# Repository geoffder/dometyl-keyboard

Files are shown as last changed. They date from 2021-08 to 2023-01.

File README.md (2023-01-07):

# Dometyl Keyboard

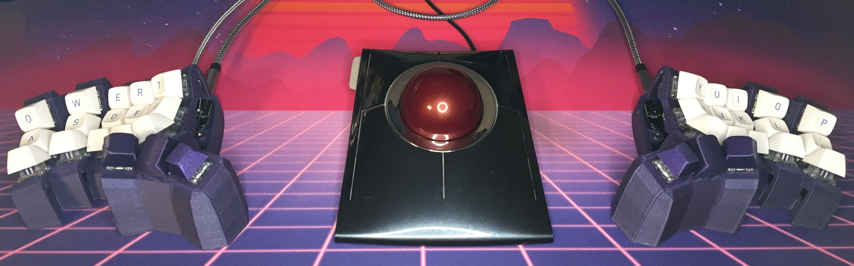
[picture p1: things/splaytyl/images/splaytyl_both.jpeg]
Splaytyl Build


## Another Dactyl inspired keyboard. Supporting MX, Choc, and even rubber domes.
This is a library for generating paramaterized split-hand, concave, columnar,
ergonomic keyboards in the spirit of the
[Dactyl](https://github.com/adereth/dactyl-keyboard), but written from the
ground up in [ocaml](https://ocaml.org/), rather than
[clojure](https://clojure.org). **Dometyl** also takes inspiration from a
lineage of **Dactyl-like** keyboards that evolved from the original script,
including the [Compactyl](https://github.com/dereknheiley/dactyl-manuform-tight)
itself a fork of forks of dactyl-manuform keyboards with many accumulated
features, and the [Skeletyl](https://github.com/Bastardkb/Skeletyl), a sleak,
low-profile, open-case design built in
[Fusion360](https://www.autodesk.ca/en/products/fusion-360/overview).

The name **(rubber) dometyl** comes from this library's introduction of a means
of building split-hand concave keyboards with rubber domes. Taking advantage of
the readily available [Niz housing and
sliders](https://www.nizkeyboard.com/products/2019-new-niz-ec-switch), and
third-party non-sheet rubber domes (e.g. [DES BKE
DOMES](https://www.apexkeyboards.ca/products/des-domes-bke-tactile)), we can
build dome-with-slider switches of our own without canabilizing an existing
Topre or Niz board. You may be thinking that we still need expensive to obtain
conical springs, and difficult to design (and *very* difficult to make use of
inside a curved case) electro capacitive sensing PCBs to complete the picture,
but then you would be wrong! One need simply glue magnets to sliders, and glue
[hall-effect sensors](https://www.diodes.com/assets/Datasheets/AH3572.pdf) into
a case, and *voila* the rubber dometyl is born.

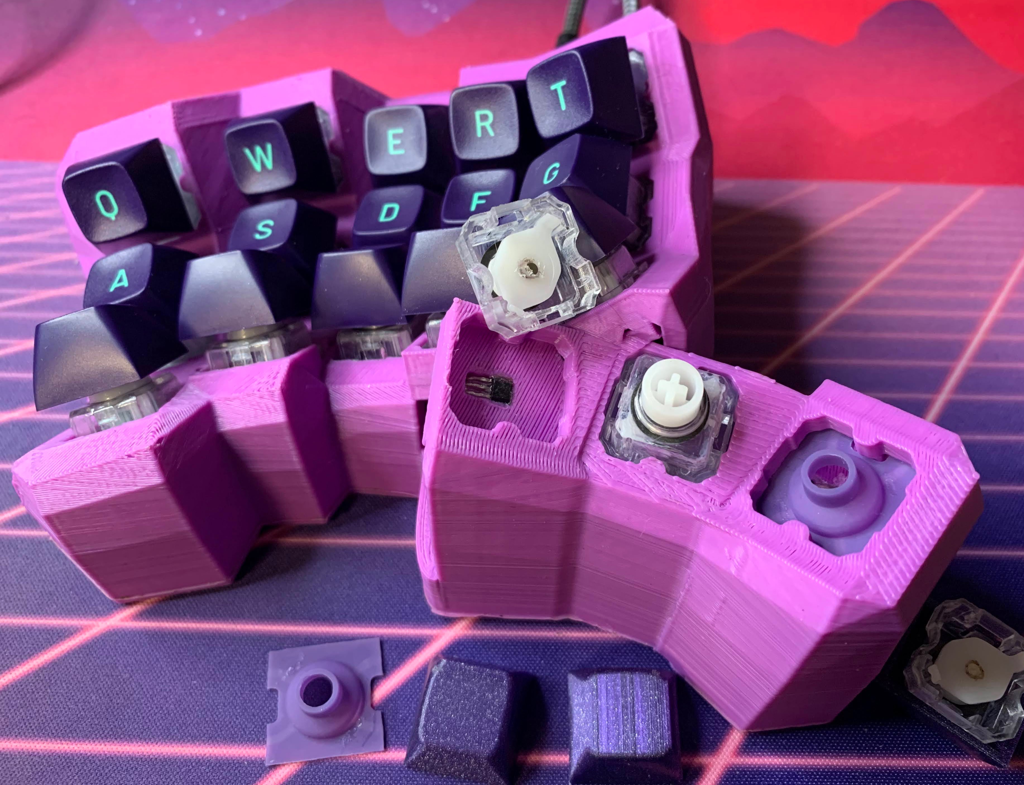
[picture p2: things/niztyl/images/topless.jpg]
niztyl - gone topless


The relevant code for generating the required keyhole can be found in the [Niz
module](lib/niz.ml), the first example of a board
configuration using them [here](models/examples/niztyl.ml), and the build
showcase for it [here](things/legacy/niztyl).

Of course, if you aren't an insane person, the dometyl generator also supports
more civilized Mx and Choc switch options.

## Setup
This generator is written in [ocaml](https://ocaml.org/), so you'll need to get
an environment set up, including the package manager
[opam](https://opam.ocaml.org/) and the build system
[dune](https://github.com/ocaml/dune) (which we'll install through opam). You'll
of course also want [OpenSCAD](https://openscad.org/) to preview/render/export
the generated models (see [OpenSCAD configuration](#openscad-configuration) for tips).

After installing `opam`, and confirming that you are in this branch, you can run
the [setup.sh](setup.sh) script for convenience, or follow the instructions
under the [opam dependencies](#opam-dependencies) sub-section.

### opam dependencies
All dependencies are available from the opam package manager including the build
system [dune](https://github.com/ocaml/dune), and of course
[OCADml](https://github.com/OCADml/OCADml),
[OSCADml](https://github.com/OCADml/OSCADml)
and [ppx_deriving_cad](https://github.com/OCADml/ppx_deriving_cad) for the
modelling. I'd also recommend that you pick up the listed dev tools (which
you'll want to get the corresponding packages/plugins for in your editor of
choice).

**Required:**
From this folder (repo root):
* `opam install . --deps-only --with-doc`
* `dune build`

**Highly recommended for dev experience:**
* `opam install merlin ocp-indent ocaml-lsp-server ocamlformat ocamlformat-rpc`

## OpenSCAD configuration
It is **highly recommended** that you use a [development snapshot](https://openscad.org/downloads.html) of OpenSCAD,
rather than whatever version your package manager may have for you. Then under
the `Features` tab in `Edit/Preferences` and check the following:
- `fast-csg`, `fast-csg-trust-corefinement`, `fast-csg-remesh`,
  `fast-csg-remesh-predictability`, `lazy-union`, `vertex-object-*`
The newly added `fast-csg` and related features speed up rendering considerably,
making the development cycle much more pleasant

## Documentation
API documentation and usage guides are available
[online](https://geoffder.github.io/dometyl-keyboard/dometyl/index.html).

## Usage
1. Make a new `.ml` file in [models](models), maybe
   starting with a copy of and existing one and and modifying it to suit your
   preferences / fit your hand.
2. Modify [main.ml](models/main.ml), adding lines to generate and write
   your case models/parts to file with `Scad.to_file`.
3. Run your [main.ml](models/main.ml) with `dune build @models` from the [dometyl](dometyl)
   project folder. Any `.scad` files produced will then appear in the
   [models](models/scads) directory. For a more fluid experience, you
   can install `fswatch` (cross-platform) or `inotify` (GNU/linux) on your
   system, and use `dune build -w @models` to automatically build and execute on
   file changes.
4. Open generated `.scad` files in OpenSCAD where they can be
   previewed/rendered/exported to `.stl`. If a viewed `.scad` is overwritten by
   compiling and running the generator, the changes will be visible in the GUI.

### Direct Export
`dune build @export_models` is also made available for convenient batch `stl`
export. When run, this rule will call out to the `openscad` cli (assumed to be
installed on your system) to asynchronously export *all* of the `scad` files in
[models](models/scads) directory to `stl` models in the
[models](models/stls) directory at once.

**Note:**
- Enabling `fast-csg` and the like is not currently supported by the `OSCADml`
  CLI helpers.
- STL export can take quite a while (which is why this can be helpful) and
 consume a lot of resources, so one should be mindful of what one is signing up
 for by building this rule.
- Unfortunately, CLI export sometimes fails in CGAL when the same model would
 pass via the GUI.

## Example Output
* An uglier [recreation](models/examples/skeletyl.ml) (yellow) of the
  [BastardKB Skeletyl v4](https://github.com/Bastardkb/Skeletyl) (purple).
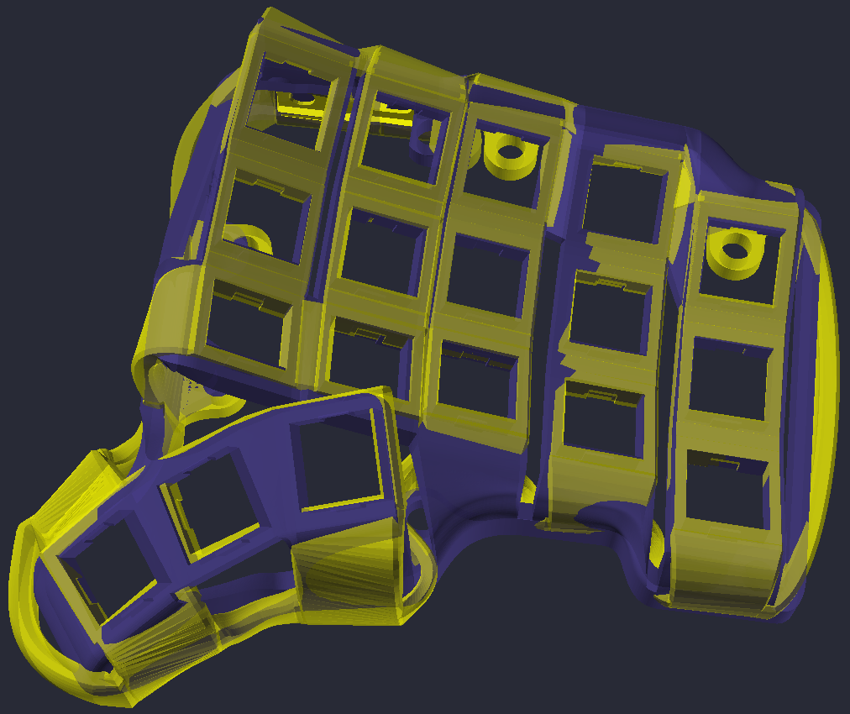
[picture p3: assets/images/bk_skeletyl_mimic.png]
bk skeletyl comparison
  
  This configuration can be a good place to start if what you are looking for is
  minor tweaks to more "standard" dactyl-like curvatures and offsets (or you want hotswap
  sockets).
* Configurable heat-set insert screw holes, magnet insets, or bumpon feet can be
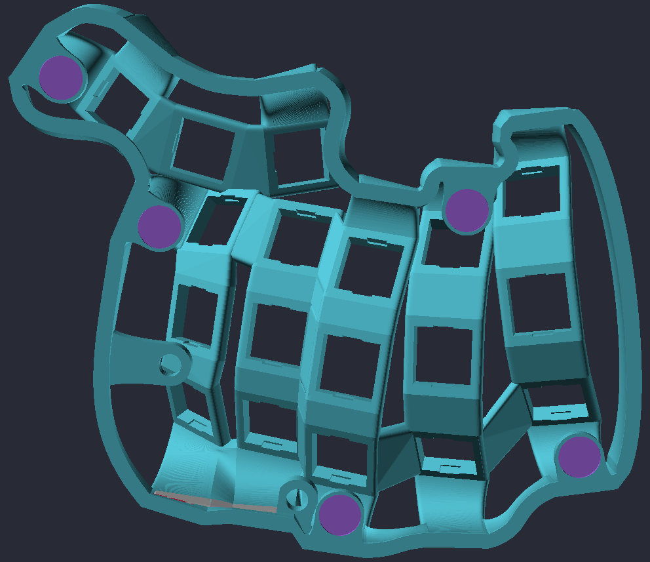
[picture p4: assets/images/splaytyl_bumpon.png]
splaytyl bumpon view
  placed at the base of walls of your choosing 
* Base plates and configurable tents can be generated to fit your case, using
  either screws (into brass insets in the case), or magnets for mounting.
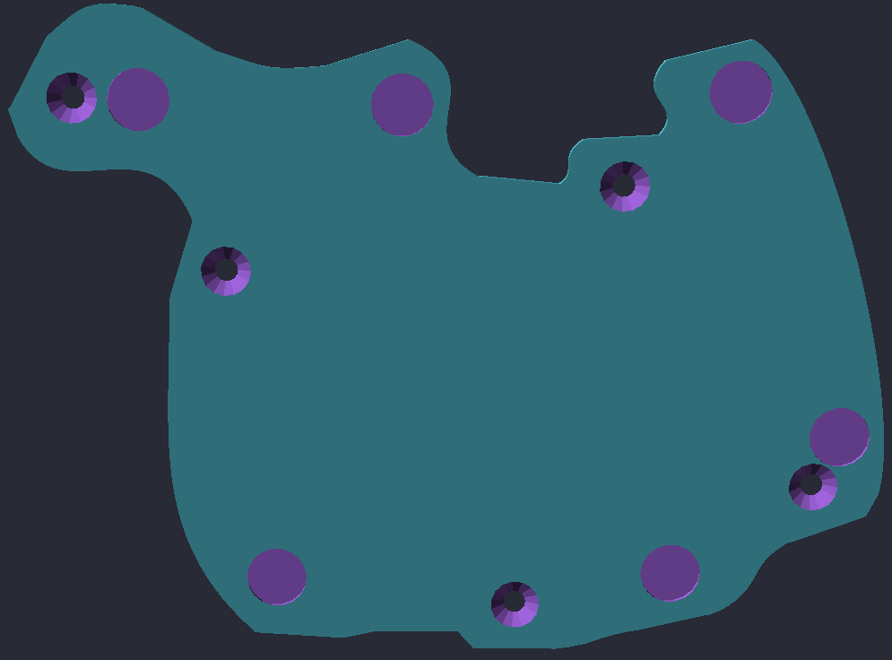
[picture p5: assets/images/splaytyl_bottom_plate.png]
splaytyl bottom plate
  
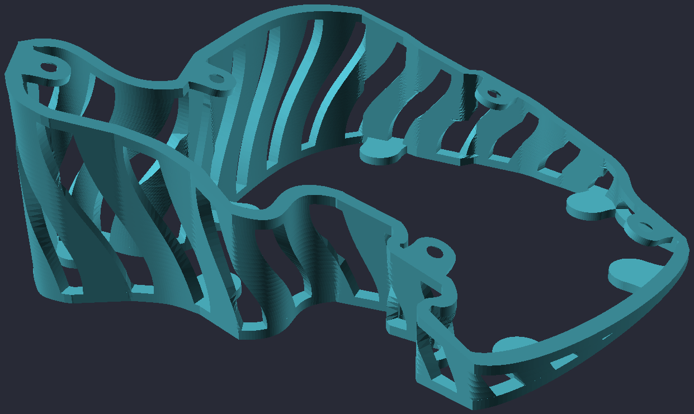
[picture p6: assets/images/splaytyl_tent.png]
splaytyl tent
  

## Builds / STLs
There is a showcase of finished builds and some example STLs [here](things), including some
pictures, bills of materials, and notes. If you've designed and built a board
with the dometyl generator, and you are happy with it, please consider contributing the
configuration to the [models](models) directory, and adding a folder
to the [boards showcase](things).

## MCU / TRRS jack holders
* A few solutions for MCU (elite-C and pro-micro currently) and TRRS jack
  mounting are available at the moment. Rough placement is done with the help of
  coordinates kept within the records of the `Case.t` type, with offset and
  rotation parameters available to fine-tune.
* Firstly, there is support for using the familiar slot-in trays from
  [dereknheiley](https://github.com/dereknheiley/dactyl-manuform-tight)
  (reversible, elite-C without and without reset button access) and
  [carbonfet](https://github.com/carbonfet/dactyl-manuform) (non-reversible,
  elite-C and pro-micro). Eventually a more tailored tray holder that should be
  available, but these existing stls can get the job done today.
* Second, the [BastardKB shield
  pcb](https://github.com/Bastardkb/Elite-C-holder) used in the
  [Skeletyl](https://github.com/Bastardkb/Skeletyl) (as well Quentin's other
  boards) is supported as well. In addition to making the required insets/holes
  in the case, the included helper functions will place configurable eyelets for
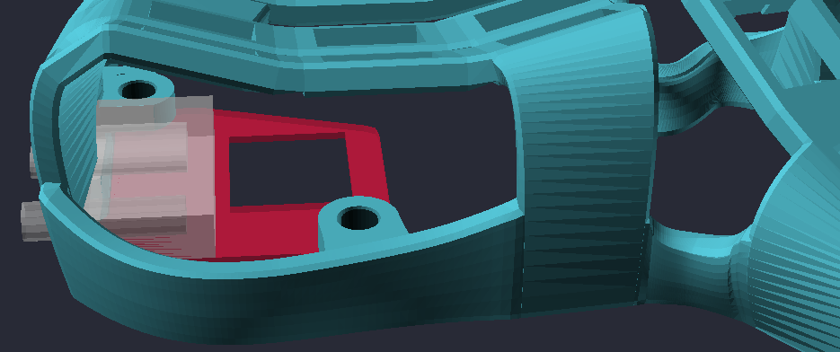
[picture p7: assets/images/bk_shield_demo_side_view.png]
BK shield side-view
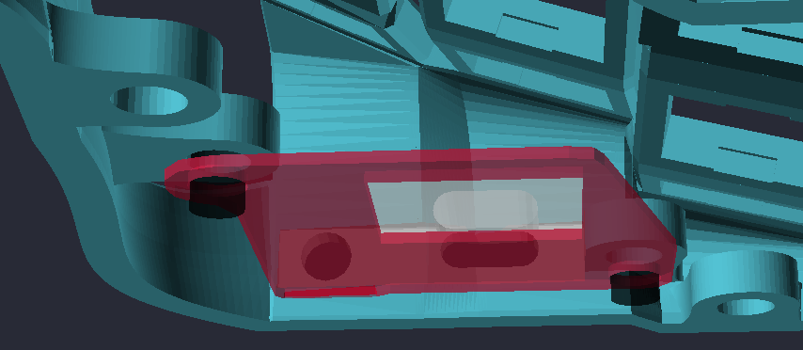
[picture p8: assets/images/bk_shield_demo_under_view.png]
BK shield under-view
  heatset inserts for mounting.  
  Some time ago, I ordered way too many of these off of JLCPCB, so if you are in
  NA, something could likely be arranged! Alternatively, if would like to use
  this mounting method rather than one of the trays, and you don't want get PCBs
  made, there is an [stl](assets/mcu_holders/bastardkb/printable_shield_right.stl)
  available which you can print and solder your components around / glue to.
* When using one of the trays, be mindful that the rails/slots are cut nicely in
  the wall, and for an option that cuts ports into the wall, be sure that they
  don't start too far away from the outside, so that the plugs will be able to
  reach. `Walls.make` has an `index_scale` parameter so that these
  holder-relevant walls can be tuned separately from the rest to adapt to your
  chosen mounting method.

## The Hand
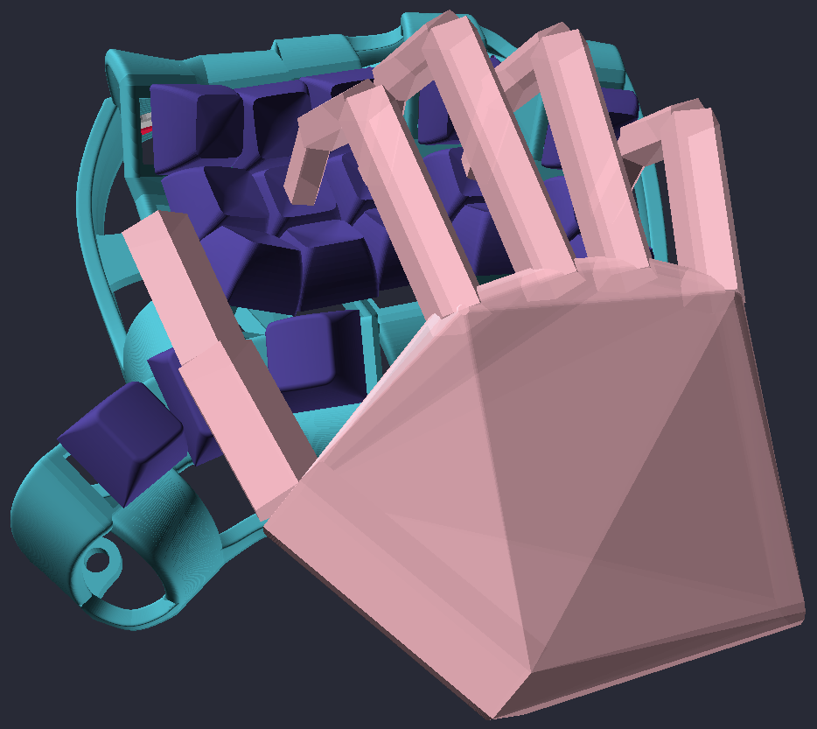
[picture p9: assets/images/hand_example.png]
Hand

There is an as yet undocumented (and subject to evolution) [Hand
module](lib/hand.ml) available to play around with. One can
generate hand from knuckle (base of proximal bones, or the meta-carpal for the
thumb) offset coordinates and bone lengths, then pose it with the available
flexion/extension/abduction/adduction/etc functions, and place it over the home
row of a generated `Plate.t`. Hopefully this can help give you a sense of what
column offsets and curvatures are going to work for you before you commit to a
test print.

## Troubleshooting
Now and then, when you attempt to render a model, part of it will disappear.
This is due to my imperfect abuse of
[OpenSCAD
polyhedrons](https://en.m.wikibooks.org/wiki/OpenSCAD_User_Manual/Primitive_Solids#polyhedron),
which can sometimes self-intersect despite the so-far built-in preventative
efforts. The walls (from keyholes to the ground) and the connections between the
walls both use polyhedrons so they are prone to breaking in this manner.

When this happens, and more than one piece of the case disappears (e.g. all of the
connections between the walls), it can be useful to narrow down which part(s) in
particular caused it, since it isn't necessarily all of them that have gone bad.
To help with this, you can use **Thrown Together** mode in the OpenSCAD GUI
(found in the **View** menu, or activated by hitting **F12**), which will show
pink where you can see into the inside of any shapes (unclosed mesh).

Generally, you should be able to fix the problem by adjusting the parameters
used for drawing the polyhedrons in question, such as scaling walls to prevent
them overlapping with eachother, adjusting resolution with `~fn` parameters, etc.

## Contributing
Contributions extending the functionality of the library (in addition to board
configurations as mentioned above) are welcome. If you plan to make a PR, please
have autoformatting working with your editor working (using the `.ocamlformat`
profile included in this repo) beforehand, and ammend/write doc comments in the
relevant interface files (already not 100% as is).

## License
Copyright © 2023 Geoff deRosenroll

The source code for generating the models is distributed under the [GNU AFFERO
GENERAL PUBLIC LICENSE Version 3](LICENSE.md).

The generated models are distributed under the [Creative Commons
Attribution-ShareAlike 4.0 International (CC BY-SA 4.0)](LICENSE-models.md).

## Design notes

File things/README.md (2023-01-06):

Some of the builds here were made with the original formulation
of the dometyl generator (preserved in the #legacy branch). For now, the old stl
files have been moved into **legacy** sub-directories, with updated stls
replacing them at the top-level of their respective directories.

The cases/parts generated by the current iteration are not *really*
fundamentally different however, so the readme guides within should still be
helpful regardless.

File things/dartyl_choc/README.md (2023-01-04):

# Dartyl Choc Edition

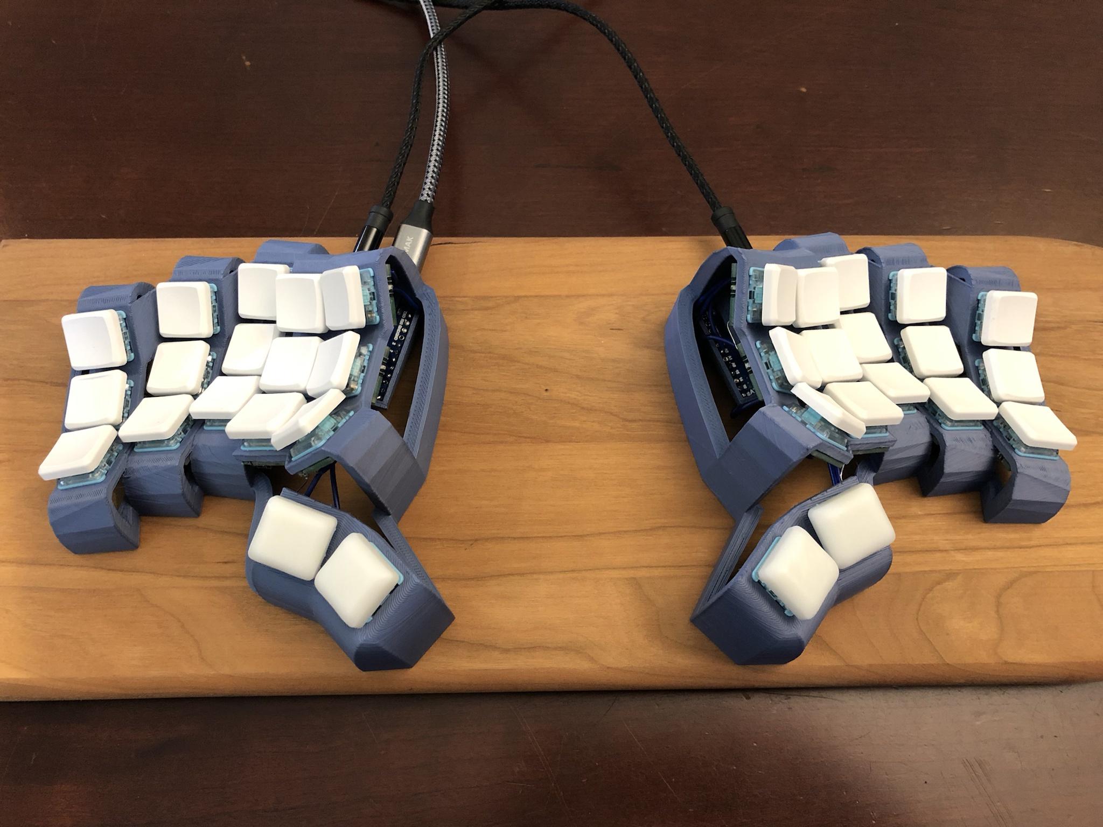
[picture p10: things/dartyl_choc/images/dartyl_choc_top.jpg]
Dartyl Choc - Top

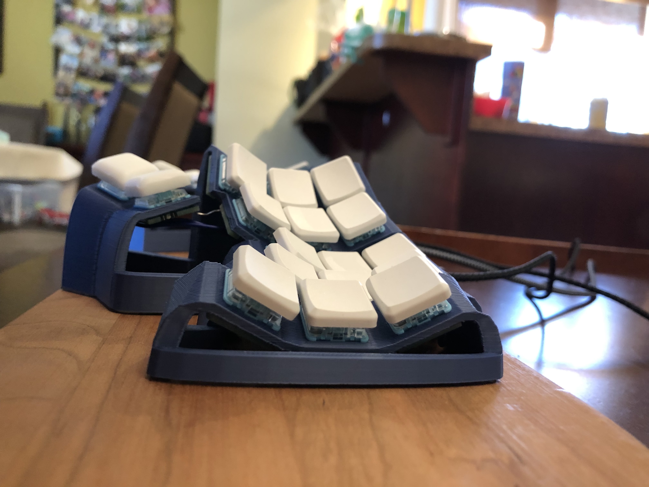
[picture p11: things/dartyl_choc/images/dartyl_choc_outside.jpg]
Dartyl Choc - Outside

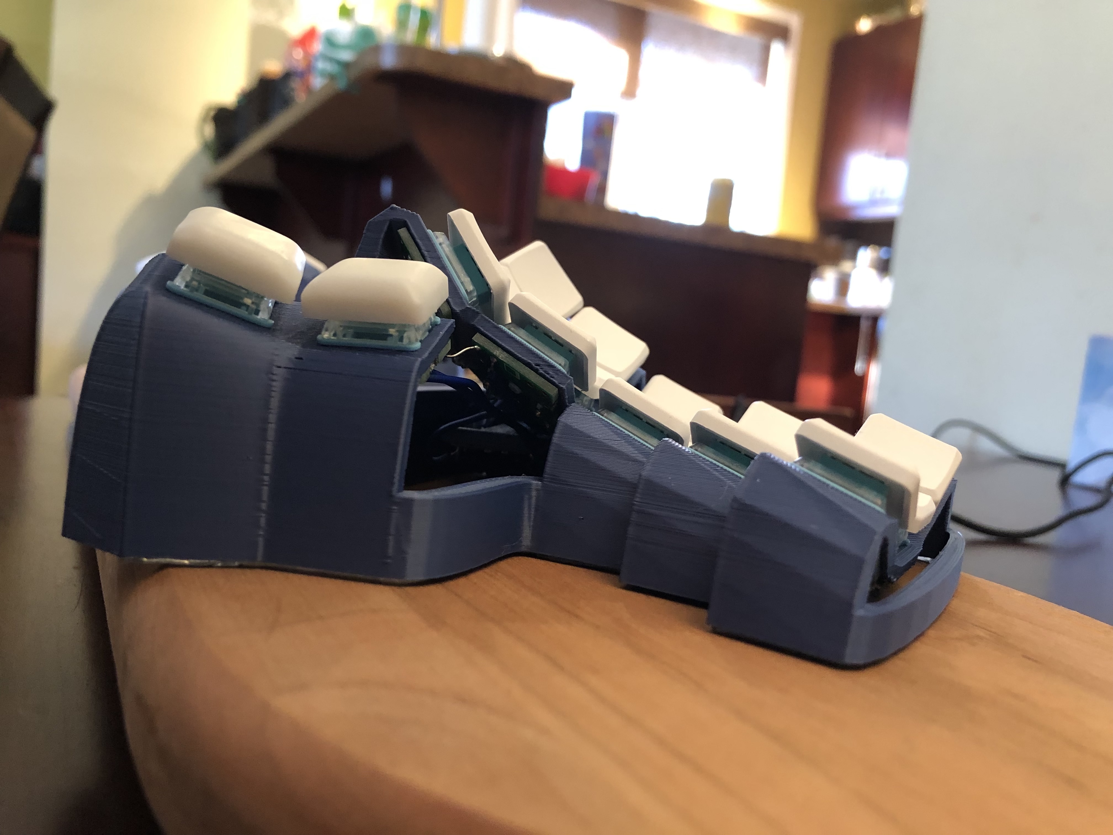
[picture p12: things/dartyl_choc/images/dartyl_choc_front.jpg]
Dartyl Choc - Front

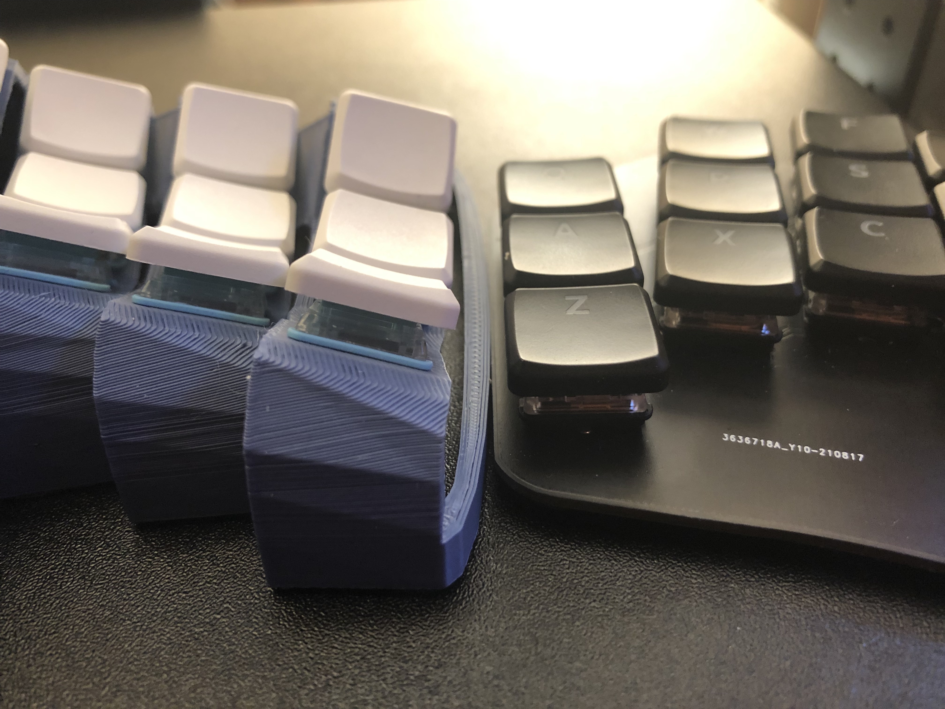
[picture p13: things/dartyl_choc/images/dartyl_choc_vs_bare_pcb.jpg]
Dartyl Choc vs. Bare PCB

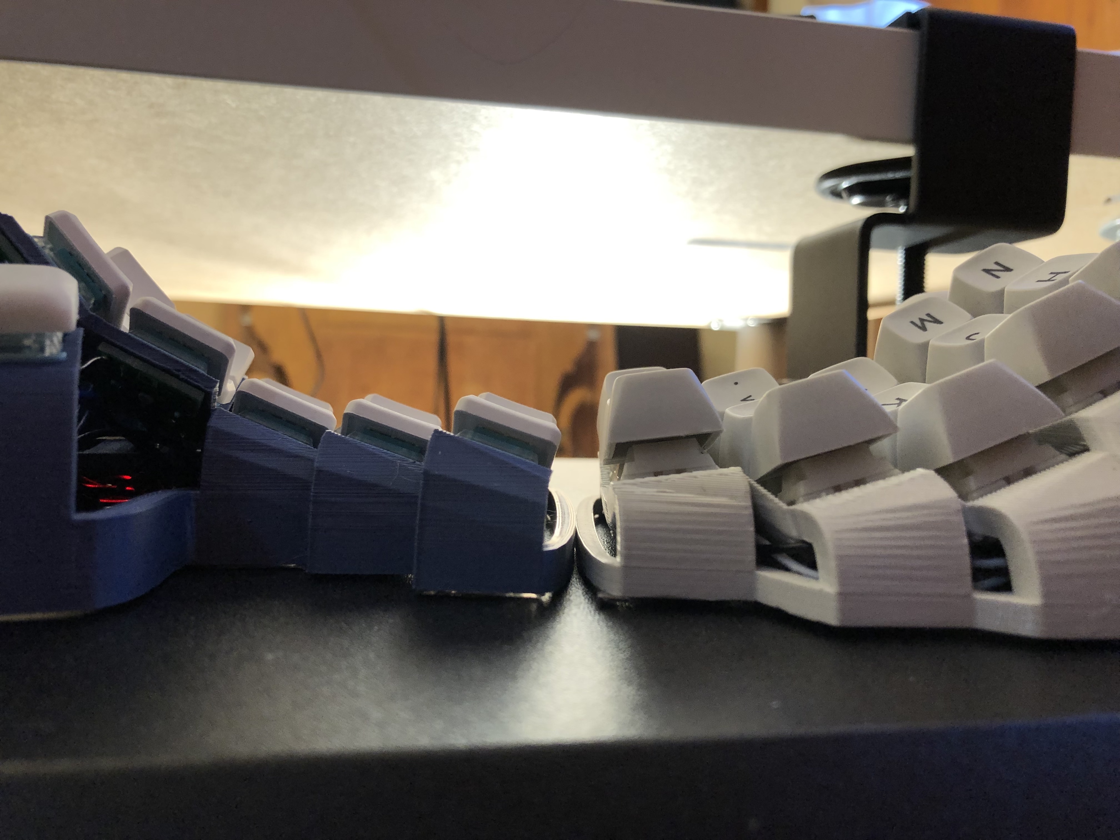
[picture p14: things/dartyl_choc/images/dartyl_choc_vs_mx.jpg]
Dartyl Choc vs. Dartyl MX

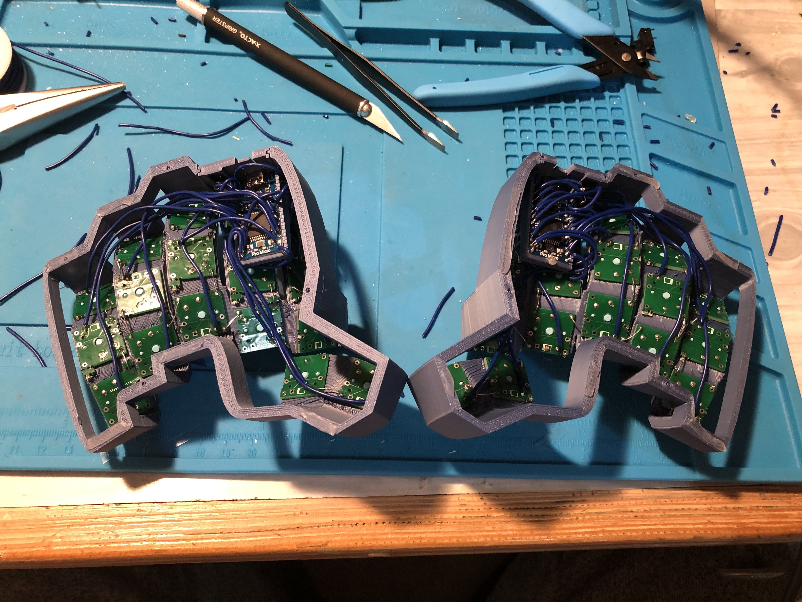
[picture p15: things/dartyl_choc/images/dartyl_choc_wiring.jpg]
Dartyl Choc - Wiring


## Bill of Materials

| Part name | Amount  |
| ---| ---|
| [Cases][case] (left and right) | 2 |
| Choc V1 switches of your choice | 34 |
| Ideally MBK caps for alphas | 30 / 34 |
| Convex thumb caps, I resin printed [these][talon] (optional) | 4 |
| Choc [1u pcb][pcb]'s (optional) | 34 |
| Pro micro compatible mcu's | 2 |
| Wires (26/28 AWG solid core wire recommended) | some |
| [Audio jack][trrs], through hole | 2 |
| USB cable for the mcu you used | 1 |
| TRRS / male-male audio cable | 1 |
| Rubber / Tape | some |
| MCU Holders (see below) | 2 |

## Wiring

This case has 34 keys which means you can use QMK's `DIRECT_PINS` feature instead of wiring a grid with diodes.

## Key Caps

I tried [talon][talon] keycaps but they didn't work with the inner column as supplied, MBK caps are the safest option.

## Grip

I used "[Reusable Double-Sided Adhesive Nano Tape][tape]" for grip and it works very well. I've also used the rubber between bumpons from a sheet of bumpons, but it's not as good.

## MCU Holders

I used a modified version of [this mcu holder](https://github.com/dereknheiley/dactyl-manuform-tight/blob/master/things/usb_holder_w_reset.stl) as the usb-c pro micros are a little longer than the regular pro micros. I've included my modified [holder stl](usb_holder_promicro_usbc.stl) and [scad](usb_holder.scad).

[talon]: https://www.thingiverse.com/thing:4858309
[pcb]: https://github.com/ibnuda/single/tree/master/choc
[trrs]: https://www.aliexpress.com/item/1005001928651798.html
[tape]: https://www.aliexpress.com/item/1005001598557779.html
[case]: dartyl_choc.stl

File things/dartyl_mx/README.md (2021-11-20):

# Dartyl MX Edition

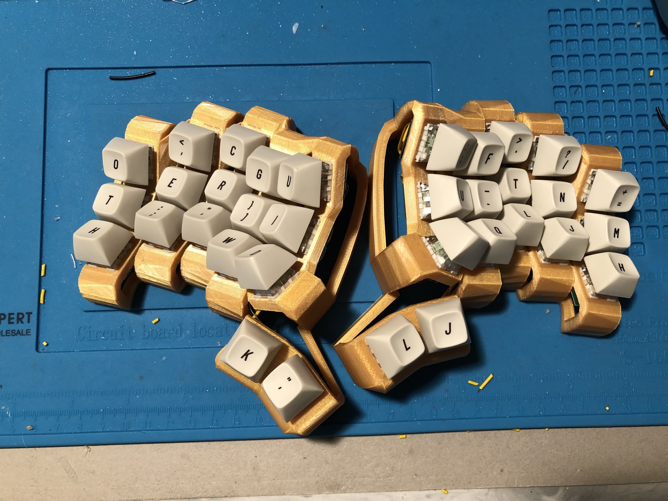
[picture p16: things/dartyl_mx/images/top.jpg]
Dartyl MX - Top


## Bill of Materials

| Part name | Amount  |
| ---| ---|
| [Cases][case] (left and right) | 2 |
| MX switches of your choice | 34 |
| Any MX compatible keycaps should work, I used MT3 | 30 / 34 |
| Convex thumb caps, I resin printed [these][convx] (optional) | 4 |
| MX [1u pcb][pcb]'s (optional) | 34 |
| Pro micro compatible mcu's | 2 |
| Wires (26/28 AWG solid core wire recommended) | some |
| [Audio jack][trrs], through hole | 2 |
| USB cable for the mcu you used | 1 |
| TRRS / male-male audio cable | 1 |
| Rubber / Tape | some |
| MCU Holders (see below) | 2 |

## Wiring

This case has 34 keys which means you can use QMK's `DIRECT_PINS` feature instead of wiring a grid with diodes.

## Key Caps

The [convex keypcap][convx] in the above BOM is credited to [pseudoku](https://github.com/pseudoku/PseudoMakeMeKeyCapProfiles) who also [sells some beautiful custom keycaps](https://www.asymplex.xyz/).

## Grip

I used "[Reusable Double-Sided Adhesive Nano Tape][tape]" for grip and it works very well. I've also used the rubber between bumpons from a sheet of bumpons, but it's not as good.

## MCU Holders

I used a modified version of [this mcu holder](https://github.com/dereknheiley/dactyl-manuform-tight/blob/master/things/usb_holder_w_reset.stl) as the usb-c pro micros are a little longer than the regular pro micros. I've included my modified [holder stl](../dartyl_choc/usb_holder_promicro_usbc.stl) and [scad](../dartyl_choc/usb_holder.scad).

[convx]: MX_DES_Convex_012tol.stl
[pcb]: https://github.com/swanmatch/MxLEDBitPCB/blob/master/readme_en.md
[trrs]: https://www.aliexpress.com/item/1005001928651798.html
[tape]: https://www.aliexpress.com/item/1005001598557779.html
[case]: dartyl_mx.stl

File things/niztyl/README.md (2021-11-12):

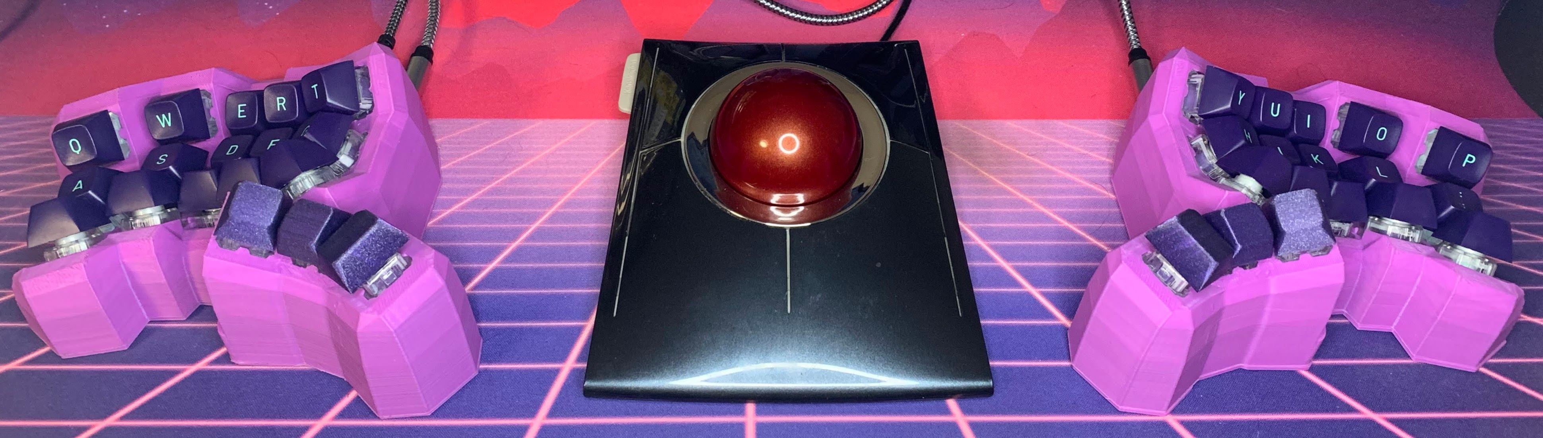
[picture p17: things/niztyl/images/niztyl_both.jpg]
Niztyl - Both Halves

Niztyl - Topless

### Overview
This is the first functional full build of a rubber dometyl. Here, magnets are
attached to the bottom of Niz stems, and brought down over omnipolar
(non-linear) hall-effect sensors directly wired to a Teensy 2.0. This
arrangement was chosen for the first build as it does not require any custom
scanning / matrix code in QMK. When I foray into my second build, I will
probably put in the work to figure out the multiplexing and custom scanning
required to use linear sensors with configurable thresholds.

### Alternate omnipolar switch and magnet combo
The listed sensor and magnet size are what I used in this build, however, the
[AH3574](https://www.diodes.com/assets/Datasheets/AH3574.pdf) with 3x1mm magnets
should also work, with a shorter possible actuation distance according to my
testing. I just went ahead with what I did out of convenience and impatience to
get the build off the ground at the time. Of key importance is that the sensor
is able to deactuate reliably before the stem tops out. The hyseresis of these
less sensitive sensors is lower relative to it's operation point than the
[AH3572](https://www.diodes.com/assets/Datasheets/AH3572.pdf), thus deactuation
can be achieved over a shorter travel distance. I believe this pairing could be
dropped in in place without modification to the case configuration and give a
better end product. Though consistent seating of the larger magnet into the
bottom of the stem will require widening out the stem dimple with your soldering
iron a bit, trading a slightly longer actuation distance for greater consistency
across your keys. If you do build a board with the AH3574s I would love to hear
how it goes.

### Bill of Materials
| Part name | Amount |
| ---|---|
| Niz EC switch housings and sliders | 36 |
| AH3572 hall effect switches (bulk - straight legs) | 36 |
| 2x1mm neodymium magnets (mine are Deryun brand) | 36 |
| Ideally MT3 caps (see [below](#caps)) | |
| Teensy 2.0 | 2 |
| Printed BastardKB shield | 2 |
| Wires (26/28 AWG solid core wire recommended) | enough |
| Hot glue | |
| M4 8mm Screw | 14 |
| M4 screw insert, (D6.0 X L5.0) or (D5.0 x L4) | 14 |
| Audio jack, SMD | 2 |
| Micro USB cable | 1 |
| TRRS / male-male audio cable | 1 |
| Adhesive steel wheel weights (optional) | |
| Bumpons / Bumper feet (10x2mm) | 12 for plates, 14 for tents |
| Lube (205 G0?) recommended (dome topouts / rattle) | |

### Switches
Some assembly is required for our switches of course. First you will need to
glue the [through-hole hall
sensors](https://www.diodes.com/assets/Datasheets/AH3572.pdf) in to the insets
in the keyholes like so:
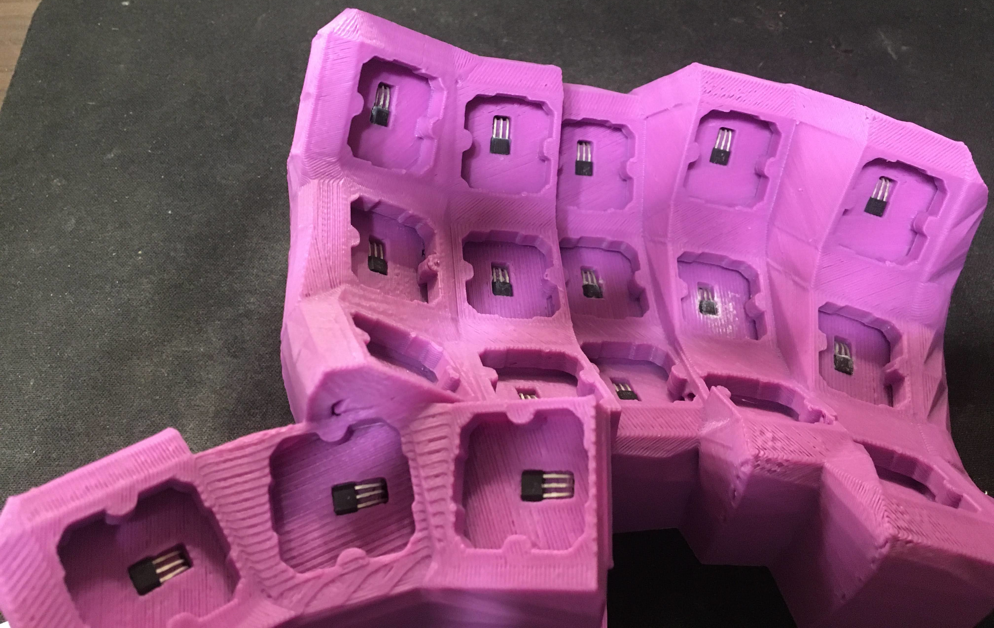
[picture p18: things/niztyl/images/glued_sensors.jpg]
glued sensors


Then, hotglue magnets to the bottom of the niz sliders like so:
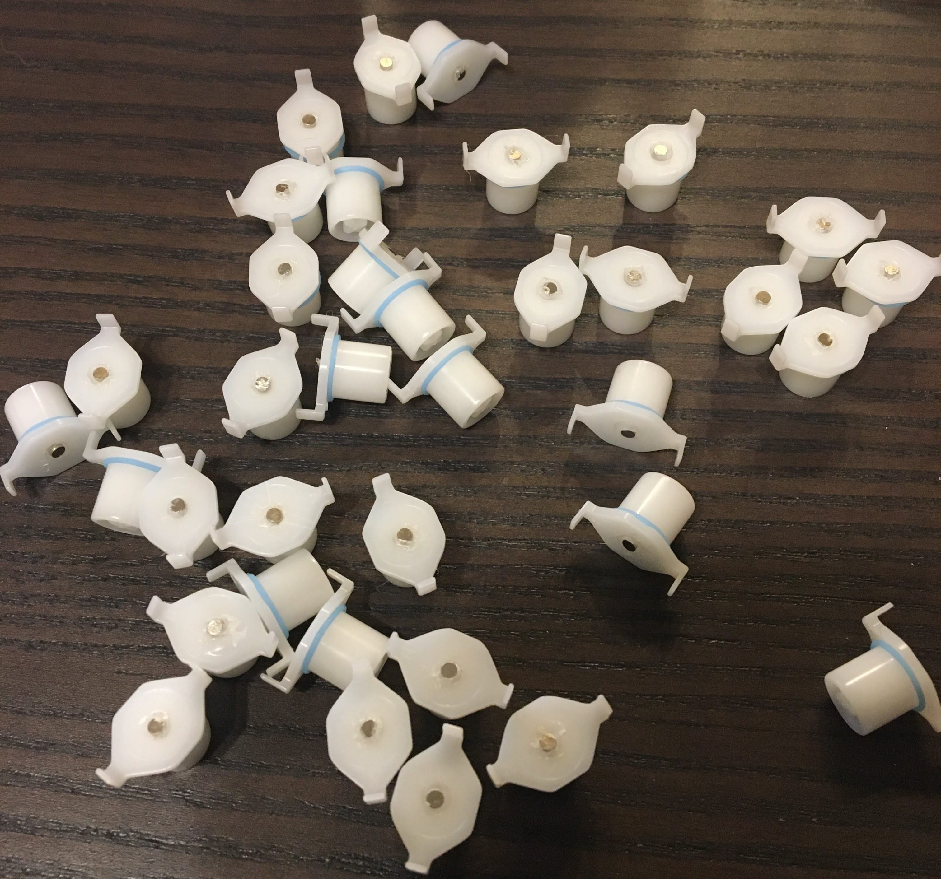
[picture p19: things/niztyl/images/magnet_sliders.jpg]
magnet sliders


Some sliders have bumps/nibs inside their spring dimple, and you'll likely want
to melt out the hole a bit with your soldering iron to seat the magnet into the
hole better. The spacing of the magnet to the sensor is important for activation
(and deactivation after hysteresis) distance, thus having relatively consistent
depth of the magnets at this stage is fairly important. Even if you have done
testing (recommended) on a breadboard with individual printed keyholes in
advance to make sure that your magnets have a suitable range with the sensors.
This can help you see if sensor inset depth adjustment (and/or rubber dome
thickness, which affects these distances, and may not match the domes that you
are using particularly well) is required for your printing setup. During your
full build, it may still happen that some angled keyholes end up with suboptimal
actuation distances (printing tolerances etc), but fortunately you will still
likely be able to jank your way out these situations just fine. If for example,
you find that a key has it's deactivation point too close to the top of the stem
travel range, leading to slow key release or failures to release, there are a
couple fixes you can readily try:

1. Check that your sensor is all the way seated into its inset (not on a thick
layer of glue) by using your iron to heat up the glue, then press down on the
sensor with some tweezers.
2. Melt a bit of more a hole into the stem to glue the magnet in deeper there

### MCU
I personally used Teensy 2.0s, as noted in the BOM above, though other controllers
that also have enough pins (more than the Pro Micro) should be fine. An Elite-C
would fit best and allow you to use a genuine BastardKB Shield rather than the
printable version subbed in here.

### MCU mounting
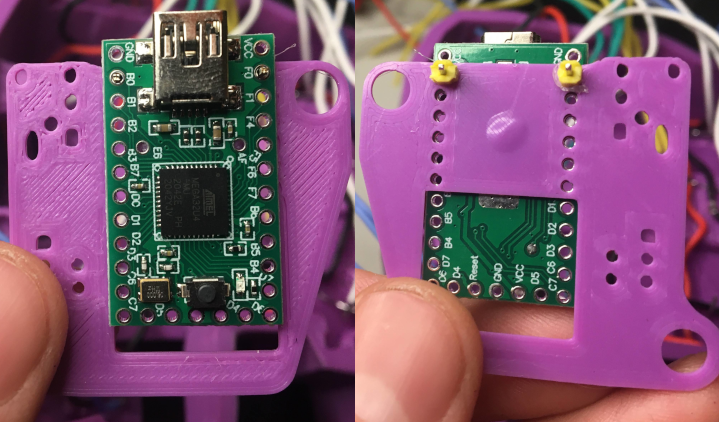
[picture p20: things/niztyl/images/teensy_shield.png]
teensy shield


M4 heatset eyelets and case cutouts are included to fit the printable BastardKB
shield. As this build is using the Teensy, which has a bit different dimensions,
I attached it to the shield with the first pins off the end of the board. This
way the USB port is able to reach through the case along with the TRS jack. To
line things up, first I soldered headers into the second set of pins, dabbed
glue down in the middle (you can see where), then placed it down while inserting
the pins into the first holes on the shield.

### Wiring
Wiring should be done using a direct pin scheme, rather than a row/column
matrix.

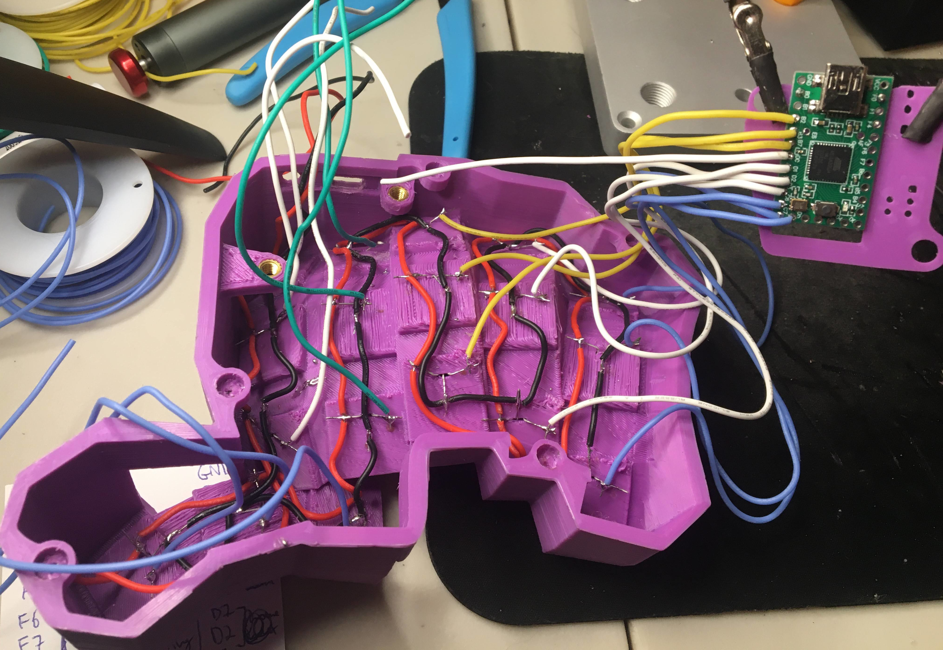
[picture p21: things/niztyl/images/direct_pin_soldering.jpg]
direct pin soldering


VCC (red) and ground (black) are wired to to pin 1 (VDD) and 2 (GND), of the
hall sensors respectively. Then, the pin 3 (OUTPUT) of each sensor is wired to
an IO pin of the MCU.

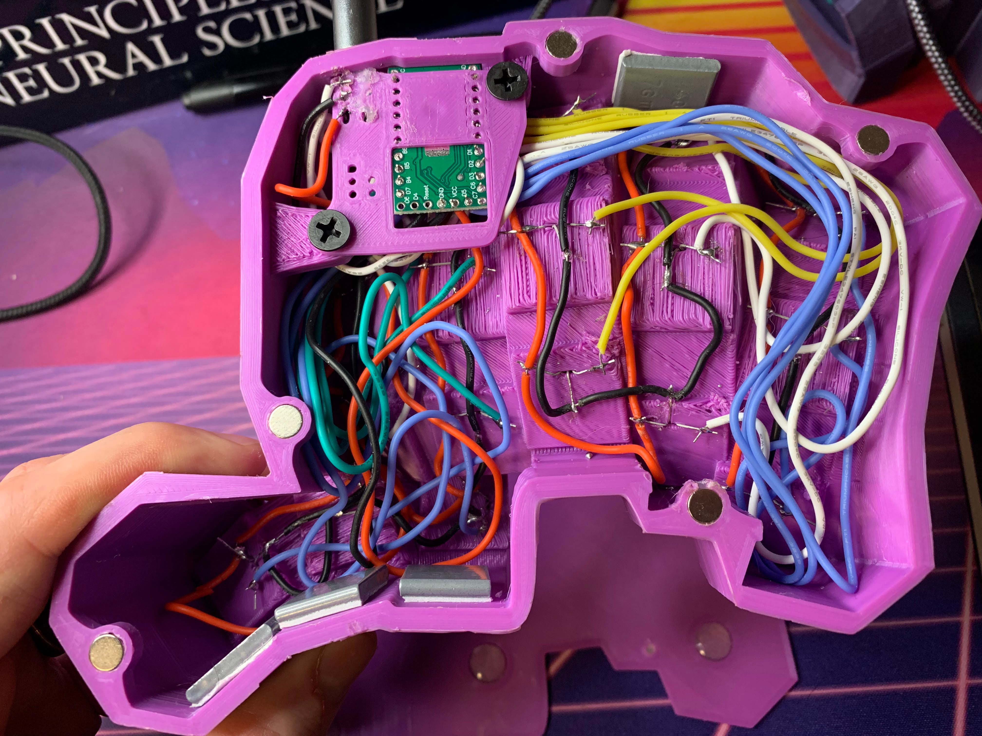
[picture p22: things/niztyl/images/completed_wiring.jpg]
wired underbelly


Please ignore the case magnets, use screws instead ([see note
below](#fasteners))! One thing that you might want to copy though, is the
inclusion of adhesive wheel weights, which add some welcome heft, and in
combination bumpons on the base plate, keep things from sliding around.

### Fasteners
As you can see in the build images, I made my first one with 6x3 magnets in the
case, with thinner 5x1 magnets in the plate. From small scale testing I didn't
think this was going to be a problem, so since I wanted to try out using magnets
(having added the option since my first build of the splaytyl) I went ahead with
them rather than screws and heatset inserts. Unfortunately, at scale with all of
the strong magnets, and the proximity of some to the keyholes, they can indeed
bias the sensors and mess with actuation distances and hysteresis. Thus, I
strongly recommend that you do as I say, and not as I do, and use screws (the
STLs here have eyelets/holes for inserts and countersunk M4s). These can be a
bit tough to access in the included 30 degree tent, but personally succeeded
after some frustration when I built my first **splaytyl**.

### Caps
The column curvatures of this configuration are made with Niz housings and MT3
caps in mind, taller caps (like SA) may collide.

### Tent
See the **Tent** section in the [splaytyl build notes](../splaytyl/README.md)

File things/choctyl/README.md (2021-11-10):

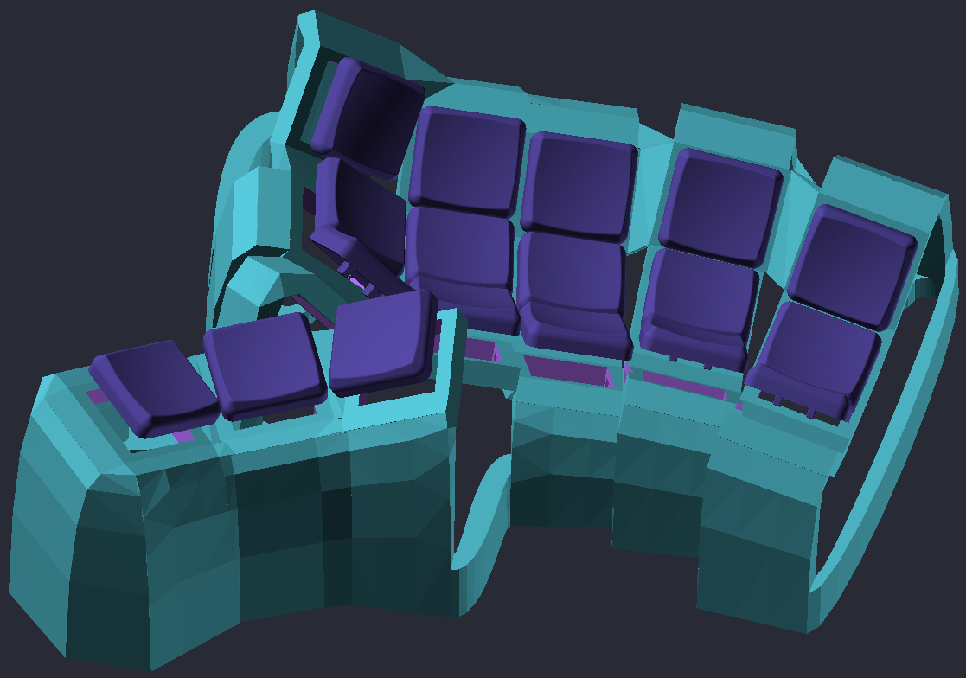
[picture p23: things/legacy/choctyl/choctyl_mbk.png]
Choctyl MBK


### Bill of Materials
| Part name | Amount |
| ---|---|
| Choc V1 switches of your choice | 36 |
| Choc V1 compatible caps | 36 |
| Kailh Hotswap Socket (if applicable) | 36 |
| Elite-C | 2 |
| Elite-C adapter PCB (>= V1.3) (or printed) | 2 |
| 1N4148 Diodes (unless direct wiring with enough pins)| 36 |
| Wires (26/28 AWG solid core wire recommended) | enough |
| 6x3 neodymium magnet | 10x case, 10x tent, 10x plate (optional) |
| 5x1 neodymium magnet (optional, for thinner plate) | 10x plate |
| Hot glue (for sockets and magnets) | |
| M4 screw insert, (D6.0 X L5.0) or (D5.0 x L4) | 4 |
| Audio jack, SMD | 2 |
| USB-C cable | 1 |
| TRRS / male-male audio cable | 1 |
| Adhesive steel wheel weights (see [**Tent**](#tent)) | |
| Bumpons / Bumper feet (10x2mm) | 12 for plates, 14 for tents |

### Switches / Caps
Designed for Choc V1, and tuned with MBK keycaps in mind (though choc cap
dimensions are likely consistent enough that you don't have to worry about
collisions with others).

### Fasteners
This example has been configured to use 6x3mm magnets (hotglued into place) for
attaching the plate and tenting base. A thinner plate generated for 5x1mm
magnets is provided as an option as well (trading sturdiness for lower height
and less plastic).

### MCU mounting
M4 heatset eyelets and case cutouts are included to fit the BastardKB Elite-C
holder.

### Tent
I recommend attaching adhesive wheel weights around the inside of the tent
(also, maybe in the case especially if you won't be using a tent) to keep it
from tipping/sliding around and make it feel sturdier. Adding some foam should
help mitigate the reverb that comes along with it, and add an extra bit of
weight as well. Example of what this may look like (from a splaytyl build):
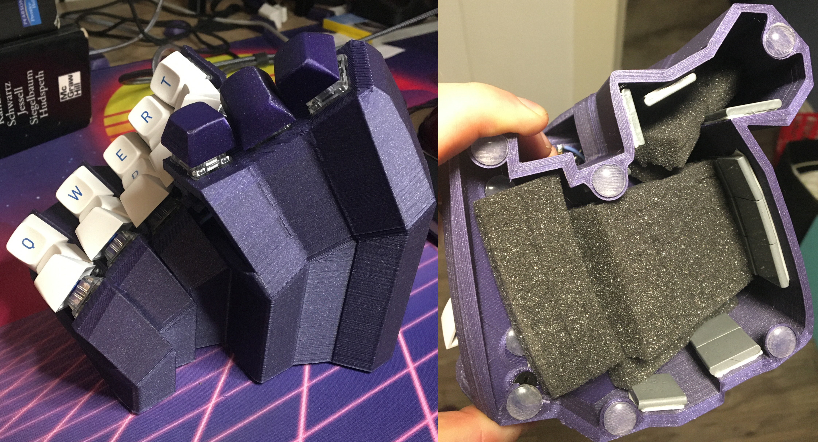
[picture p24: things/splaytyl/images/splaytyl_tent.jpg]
Splaytyl - 30deg Tent


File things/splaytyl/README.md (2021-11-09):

Splaytyl - Both Halves
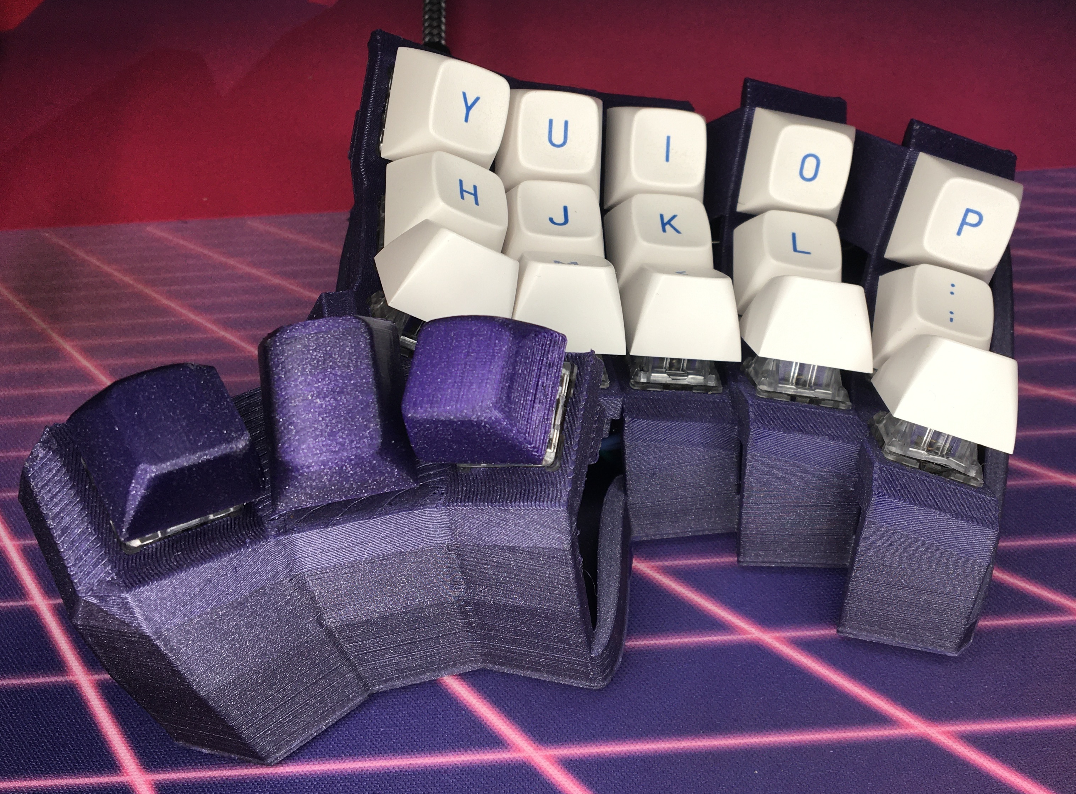
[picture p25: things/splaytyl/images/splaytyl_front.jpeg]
Splaytyl - Front

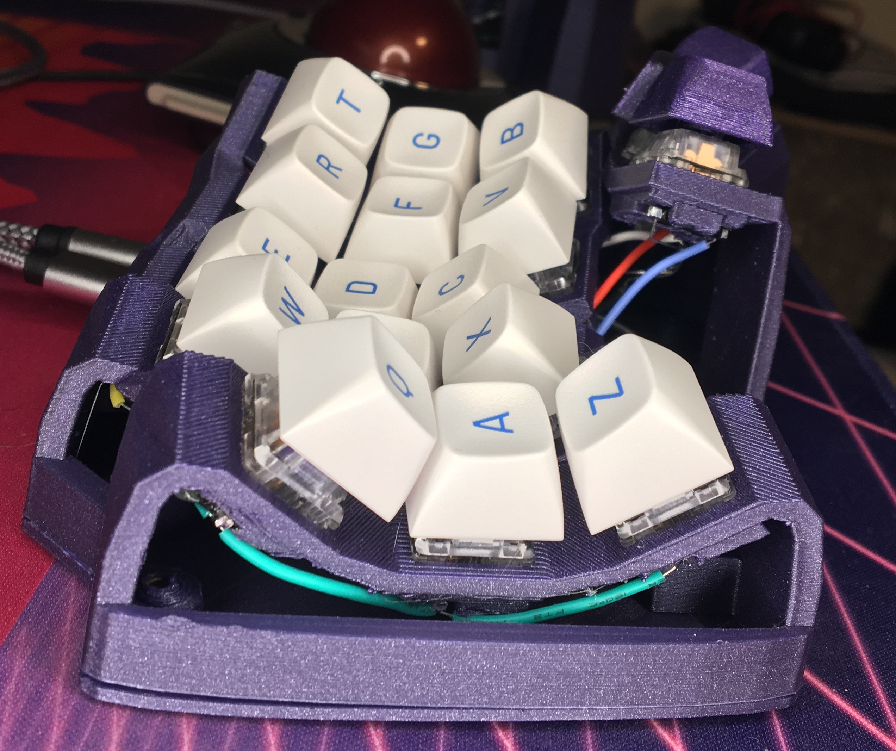
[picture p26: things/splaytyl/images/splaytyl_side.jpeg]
Splaytyl - Side


### Bill of Materials
| Part name | Amount |
| ---|---|
| MX switches of your choice | 36 |
| Ideally MT3 caps (see [below](#switches--caps)) | |
| Kailh Hotswap Socket (if applicable) | 36 |
| Elite-C | 2 |
| Elite-C adapter PCB (>= V1.3) | 2 |
| 1N4148 Diodes | 36 |
| Wires (26/28 AWG solid core wire recommended) | enough |
| M4 8mm Screw | 14 |
| M4 screw insert, (D6.0 X L5.0) or (D5.0 x L4) | 14 |
| Audio jack, SMD | 2 |
| USB-C cable | 1 |
| TRRS / male-male audio cable | 1 |
| Adhesive steel wheel weights (see [**Tent**](#tent)) | |
| Bumpons / Bumper feet (10x2mm) | 10 for plates, 12 for tents |

### Switches / Caps
The column curvatures of this configuration are made with MX switches and MT3
caps in mind, taller caps (like SA) be in collision.

### Fasteners
This example has been configured to use countersunk M4 screws and corresponding
heatset inserts (I have both the sizes listed above, and either of them work).
These can be a bit tough to access in the included 30 degree tent, but
personally succeeded after some frustration. Then, I added the option for magnet
insets, which I recommend you use instead (by firing up the generator) if you
intend to use a tenting base.

### MCU mounting
M4 heatset eyelets and case cutouts are included to fit the BastardKB Elite-C
holder.

### Tent
As noted under [**Fasteners**](#fasteners), attaching the 30 degree tent is a bit tricky due
to the cramped angles, but I was able to get it on (without the holes through
the side). I recommend attaching adhesive wheel weights around the inside of the
tent to keep it from tipping around and make it feel sturdier. Adding some foam
should help mitigate the reverb that comes along with it, and add an extra bit
of weight as well.
Splaytyl - 30deg Tent

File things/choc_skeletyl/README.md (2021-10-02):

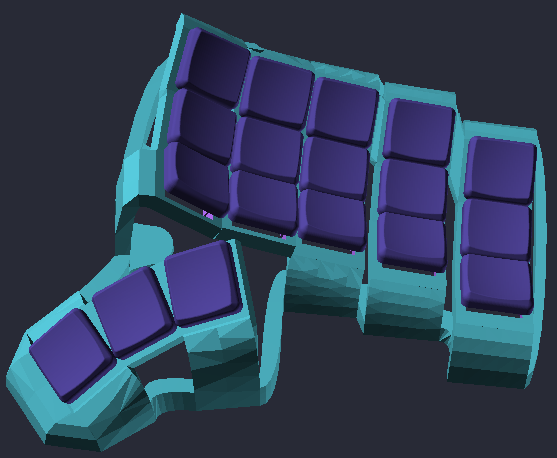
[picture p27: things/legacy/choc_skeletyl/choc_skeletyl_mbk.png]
Choc Skeletal MBK


### Switches / Caps
Designed for Choc V1, and tuned with MBK keycaps in mind (though choc cap
dimensions are likely consistent enough that you don't have to worry about
collisions with others).

### Fasteners
This configuration is designed to be low-profile, with bumpon eyelets directly
on the case, in lieu of eyelets for attaching a plate or tenting base.

### MCU mounting
M4 heatset eyelets and case cutouts are included to fit the BastardKB Elite-C
holder.

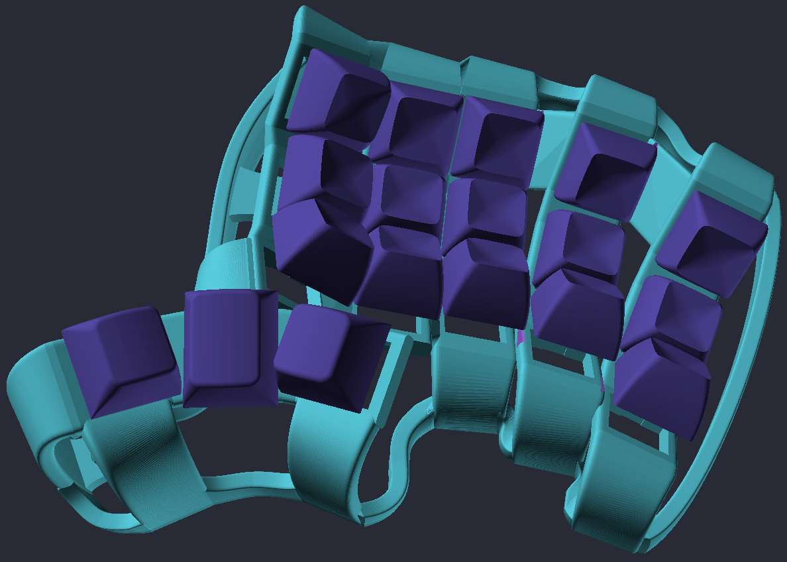
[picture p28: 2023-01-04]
docs/assets/splaytyl_with_caps.png

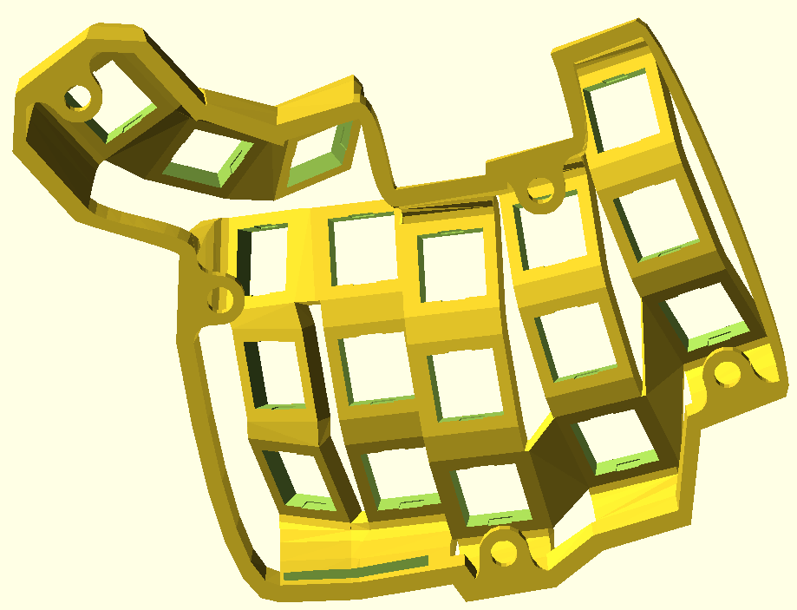
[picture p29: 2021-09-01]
assets/images/splaytyl_screw_view.png

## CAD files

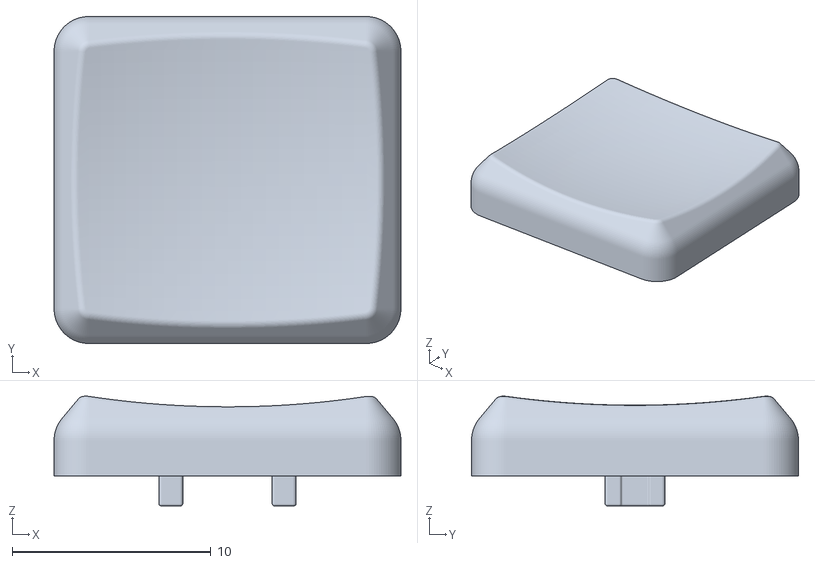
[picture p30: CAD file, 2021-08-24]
assets/caps/darryldh_MBK/MBK_1u.stl
17.5 x 16.5 x 5.52

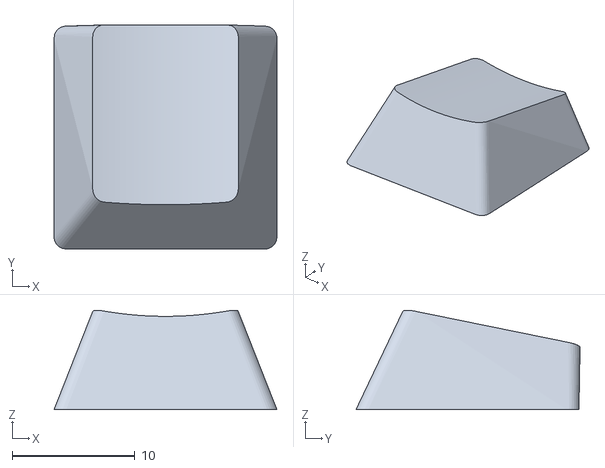
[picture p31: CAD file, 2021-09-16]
assets/caps/KeyV2_cherry/cherry-R4.stl
18.2 x 18.3 x 8.10

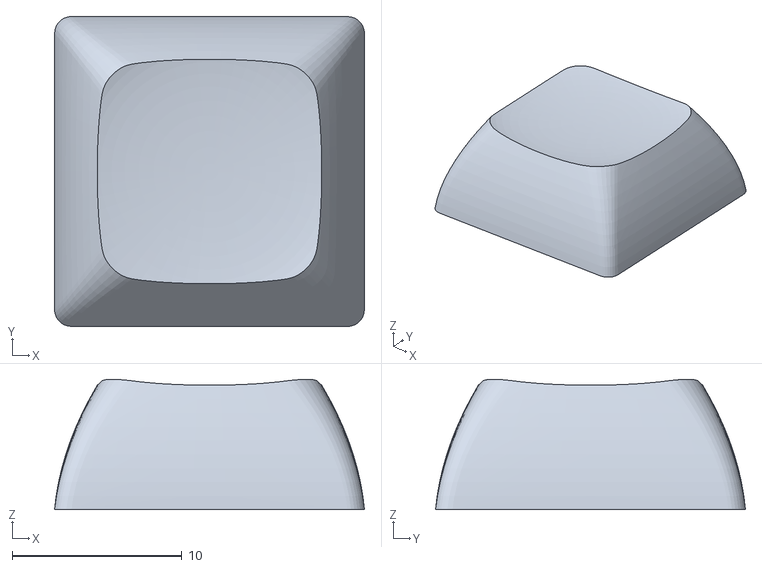
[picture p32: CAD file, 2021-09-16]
assets/caps/KeyV2_DSA/DSA-R3.stl
18.2 x 18.2 x 7.67

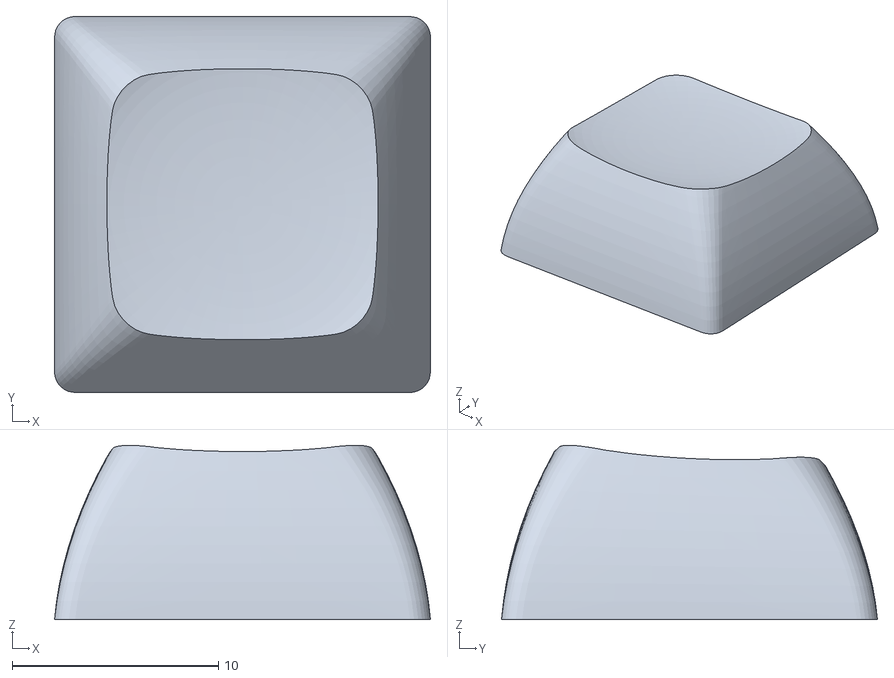
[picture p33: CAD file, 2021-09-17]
assets/caps/KeyV2_DSS/DSS-R2.stl
18.2 x 18.2 x 8.46

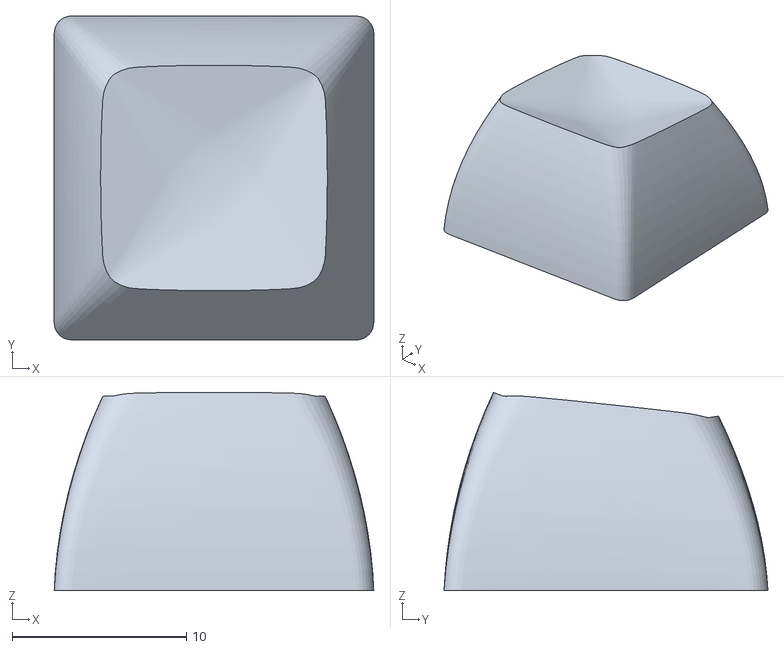
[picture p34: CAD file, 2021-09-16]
assets/caps/KeyV2_matty3/matty3-deep-R3.stl
18.3 x 18.6 x 11.4

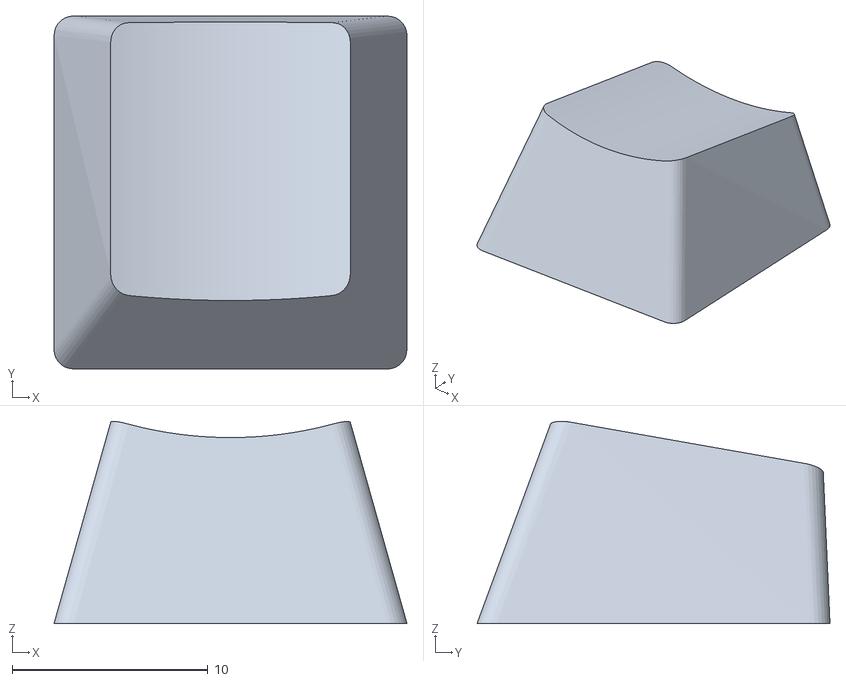
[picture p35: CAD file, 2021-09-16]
assets/caps/KeyV2_OEM/OEM-R4.stl
18.0 x 18.0 x 10.3

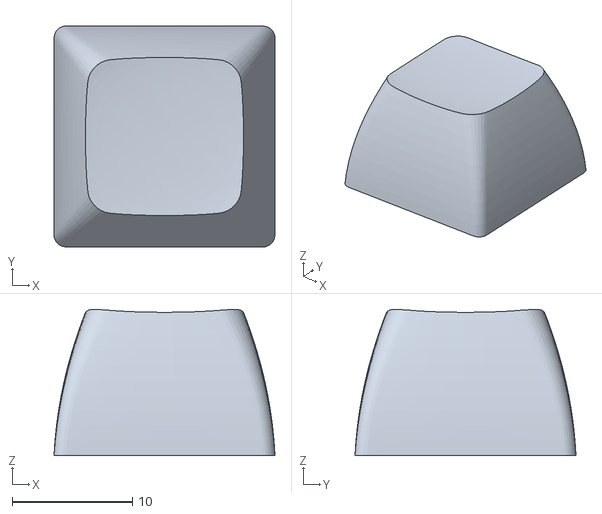
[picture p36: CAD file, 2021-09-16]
assets/caps/KeyV2_SA/SA-R3.stl
18.4 x 18.4 x 12.2

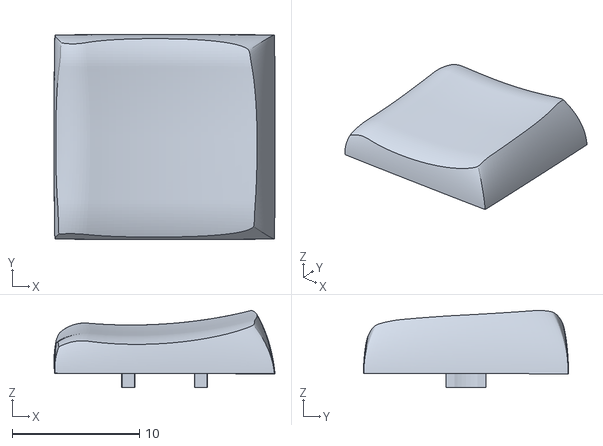
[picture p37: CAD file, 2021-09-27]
assets/caps/Pseudoku_Chicago/Chicago-thumb-1u.stl
17.4 x 16.1 x 6.05

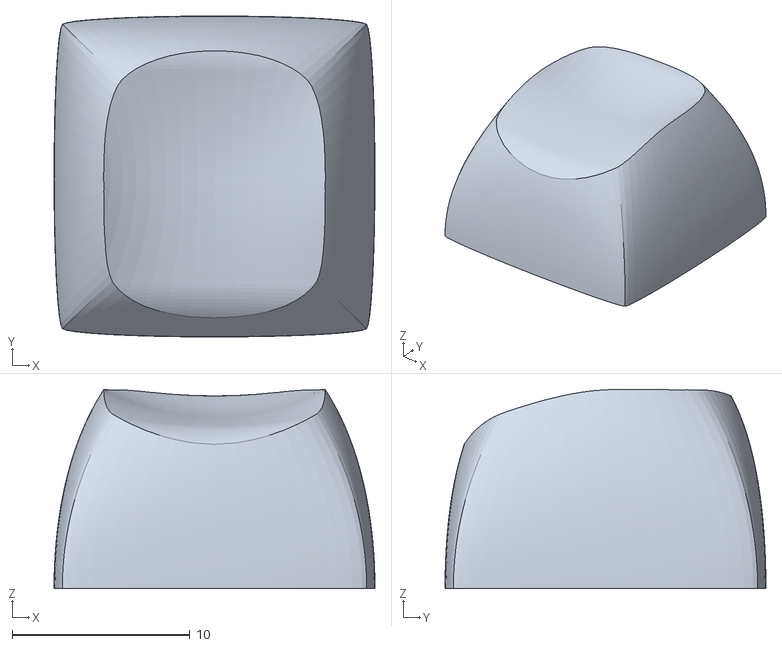
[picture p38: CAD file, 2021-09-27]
assets/caps/Pseudoku_DES/standard/DES-R5.stl
18.1 x 18.1 x 11.2

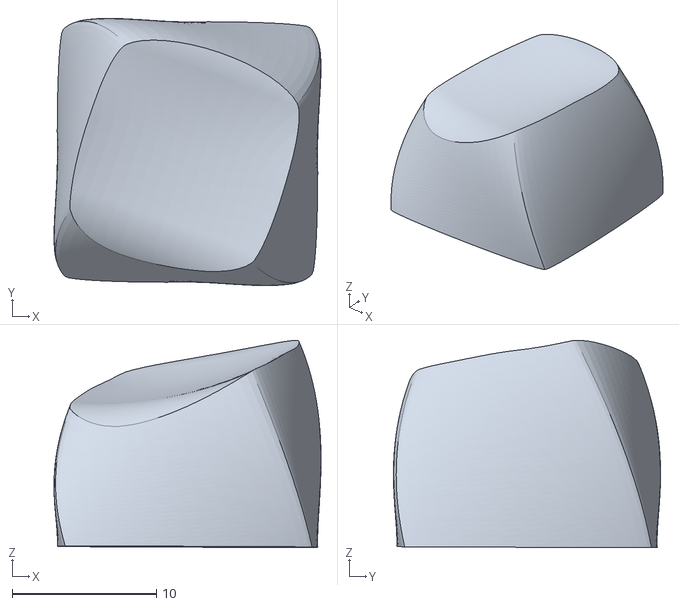
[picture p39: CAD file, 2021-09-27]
assets/caps/Pseudoku_DES/thumb/DES-kyria-R1T3.stl
18.5 x 18.5 x 14.4

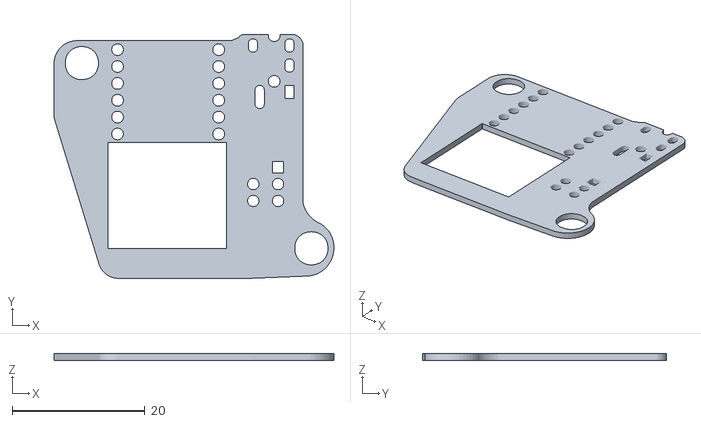
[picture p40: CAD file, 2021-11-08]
assets/mcu_holders/bastardkb/printable_shield_left.stl
42.2 x 36.8 x 1.00

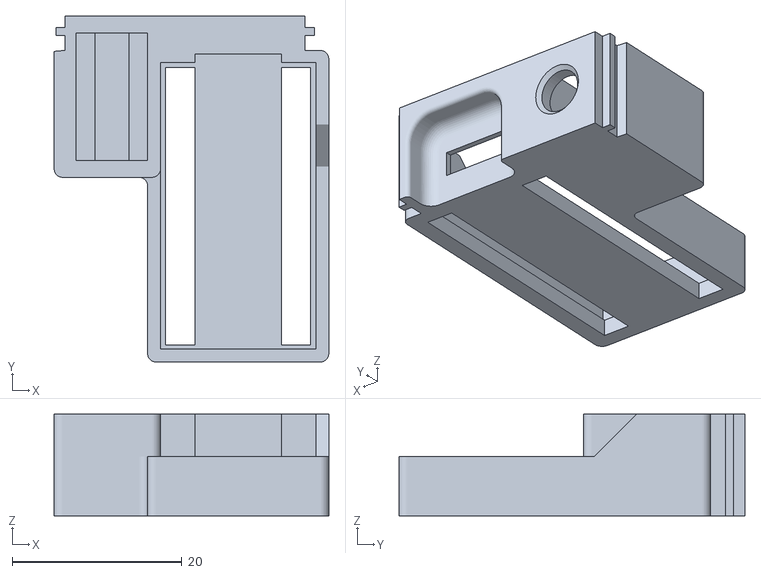
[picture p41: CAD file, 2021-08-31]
assets/mcu_holders/carbonfet/pro_micro_holder.stl
32.4 x 40.8 x 12.0

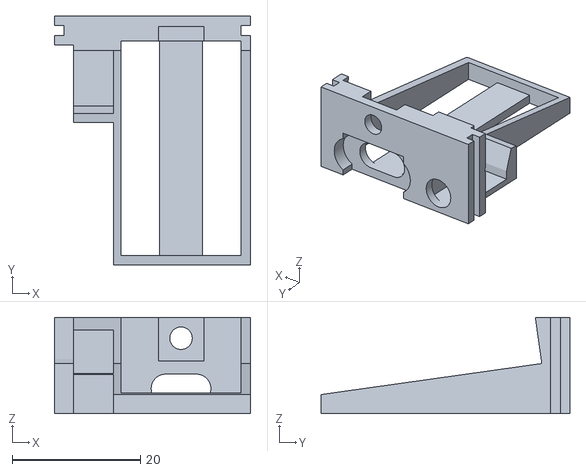
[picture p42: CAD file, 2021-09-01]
assets/mcu_holders/dereknheiley/elite-c_holder_w_reset.stl
30.6 x 38.8 x 15.0

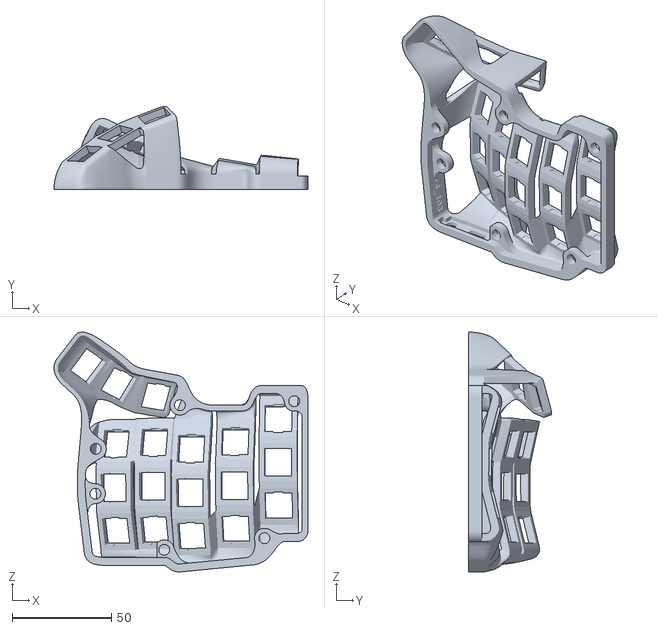
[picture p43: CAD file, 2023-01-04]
assets/other_dactyls/bastardkb_skeletyl_v4_103.stl
128.0 x 42.0 x 120.9

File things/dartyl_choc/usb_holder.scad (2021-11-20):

/* there's tons of magic numbers here because 
 * i exported a semi-done parametric version from clojure
 * and didn't fix all the formulas for x and y translates....
 * before getting it fully working and for getting how the working scad version
 * diverged from the clojure version.......................
 *
 * sorry future person trying to change this, you will need 
 * a strong dragon spear to modify any 'kinda adjustable' values */

reset_holder = true;

usb_holder_x = 30.6;       // kinda adjustable
usb_holder_y = 40.3;       // kinda adjustable
usb_holder_z = reset_holder? 15 : 8.4;        // kinda adjustable


usb_holder_border = 1.5;   // kinda adjustable

/* this combination of controller and usb_c dimensions 
 * friction fits both generations of elite-c controllers */
usb_elite_c_x = 18.7;      // kinda adjustable
usb_elite_c_y = 35.4;      // mostly adjustable
usb_elite_c_side_cut = 6;  // adjustable

usb_c_x = 9.3;             // adjustable
usb_c_z = 4.5;             // kinda adjustable

trrs_x = 6.2;              // mostly adjustable
trrs_y = 12.7;             // kinda adjustable
trrs_r = 2.55;             // adjustable

usb_holder_center_x = usb_holder_x / 2;
usb_holder_center_y = usb_holder_y / 2;
usb_holder_center_z = usb_holder_z / 2;

usb_holder_notch_xy = usb_holder_border;
usb_holder_notch_down = usb_holder_border * usb_holder_notch_xy;
usb_holder_notch_half = usb_holder_notch_xy / 2;

$fn = 100;

module basicShape() {
  difference () {
      //basic starting shape to cut away from  `
      cube ([usb_holder_x, usb_holder_y, usb_holder_z], center=true);
      
      left_cut_x = 2 * usb_holder_border;
      left_cut_y = 3 * usb_holder_border;
      
      bottom_cut_x = (left_cut_x + trrs_x);
      bottom_cut_y = (left_cut_x + trrs_x);
      
      cut1_x = (usb_holder_center_x -  usb_holder_border);
      cut1_y = (usb_holder_center_y - (usb_holder_center_y - left_cut_y/2));
      
      cut2_x = (usb_holder_center_x - (bottom_cut_x / 2));
      cut2_y = (usb_holder_center_y - (- usb_holder_center_y (16.6 / 2))); //todo
      
      //misc magic numbers
     union () {
        translate ([-cut1_x, -cut1_y, 0]) {
          cube ([left_cut_x, (usb_holder_y - left_cut_y), 99], center=true);
        }
        translate ([-cut2_x, -8.3, 0]) {
          cube ([bottom_cut_x, (usb_holder_y - 16.6), 99], center=true);
        }
        rotate (a=8, v=[1, 0, 0]) {
          top_cut_adjust = reset_holder? 1.75*usb_holder_border : usb_holder_border;
          translate ([0, -(usb_holder_border * 3), (usb_holder_z / top_cut_adjust) ]) {
            cube ([usb_holder_x, usb_holder_y, usb_holder_z], center=true);
          }
        }
      }
    
    // side notches that key into other object
    notch_x = (usb_holder_center_x - usb_holder_notch_half);
    notch_y = (usb_holder_center_y - usb_holder_notch_down);
    translate ([ notch_x, notch_y, 0]) { notch(); }
    translate ([-notch_x, notch_y, 0]) { notch(); }

    
    translate([  -30, -34.6,  0.4]) cube([50, 50, 50]);

//    rotate([3, 0, 0]) translate([  -25, -28.5,  -58]) cube([50, 50, 50]);
  }
}
module notch() {
    ///rotate([2, 0, 0])
    cube ([usb_holder_notch_xy, usb_holder_notch_xy, 99], center=true);
}

module trrsCutouts() {
    trrs_floor = 1;
    trrs_squareCutoutHeight = 12;
    trrs_squareCutoutHeightOffset = trrs_floor - usb_holder_center_z + trrs_squareCutoutHeight/2;
    translate ([-9.2, 12.65, trrs_squareCutoutHeightOffset]) {
        cube ([trrs_x, trrs_y, trrs_squareCutoutHeight], center=true);
    }
    
    trrsAngle_z_adjust = reset_holder? 0.5 : 4;
    trrsAngle_z_factor = reset_holder? 0.5 : 1;
    translate ([-9.2, 11.65-trrs_y/3, trrsAngle_z_adjust * usb_holder_border]) {
        rotate (a=-72.0, v=[1, 0, 0]) {
            cube ([trrs_x, trrs_y, usb_holder_z * trrsAngle_z_factor], center=true);
        }
    }
    
    trrs_y_offset = (usb_holder_center_y - (usb_holder_border / 2) +0.01);
    trrs_z_offset = (usb_holder_center_z - (trrs_floor + trrs_r));
    translate ([-9.1, trrs_y_offset, -trrs_z_offset]) {
        rotate (a=90.0, v=[1, 0, 0]) {
          cylinder (h=(usb_holder_border * 2), r=trrs_r, center=true);
        }
    }
}

module resetCutout() {
    reset_xz = 7.1;
    reset_y = 4.5;
    reset_floor = usb_holder_z / 1.5 ;
    reset_r = 1;
    
    reset_x_offset = usb_holder_center_x - usb_elite_c_x / 2 - usb_holder_border;
    reset_y_offset = usb_holder_center_y - usb_elite_c_y - usb_holder_border - 3.8;
    reset_z_offset = usb_holder_center_z - (reset_floor + reset_r);
    

    translate ([reset_x_offset, -reset_y_offset, -reset_z_offset]) {
        cube ([reset_xz, reset_y, reset_xz], center=true);
    }
    
    // translate ([reset_x_offset, 0, -reset_z_offset]) {
    //     rotate (a=90.0, v=[1, 0, 0]) {
    //       cylinder (h=99, r=reset_r, center=true);
    //     }
    // }
}

module eliteC() {
    x_offset = ( (usb_holder_center_x - (usb_elite_c_x / 2)) - usb_holder_border);
    y_offset = (-(usb_holder_center_y - (usb_elite_c_y / 2)) + usb_holder_border)-0.5;
    z_offset = usb_holder_border;
    
    
    
    
    
    
    translate ([x_offset, y_offset, z_offset]) {
        cube ([usb_elite_c_x, usb_elite_c_y, usb_holder_z], center=true);
    }

    left_cut_x  = ((usb_holder_center_x - (usb_elite_c_x / 2)) - ((usb_elite_c_x / 2) - (usb_elite_c_side_cut / 2)) - usb_holder_border);
    right_cut_x = ((usb_holder_center_x - (usb_elite_c_x / 2)) + ((usb_elite_c_x / 2) - (usb_elite_c_side_cut / 2)) - usb_holder_border);
    translate ([left_cut_x , y_offset, 0]) { circuitBoardSlots(); }
    translate ([right_cut_x, y_offset, 0]) { circuitBoardSlots(); }

    usbPort_z_adjust = reset_holder? -3.0 : -1.3;
    translate([0, 3, usbPort_z_adjust]) {
        usbPortCutout();
        usbRecessCutout();
    }
}

module circuitBoardSlots() {
    cube ([usb_elite_c_side_cut, usb_elite_c_y, 99], center=true);
}

module usbPortCutout() {
    usbPortCenter = ((usb_holder_center_x - (usb_elite_c_x/2)) - usb_holder_border);
    usbPortCenterCut = (usb_c_x - usb_c_z);
    usbPortSideOffset = usbPortCenterCut / 2;
    usbPortCenterCutLength = 35;
    
    translate ([(usbPortCenter - usbPortSideOffset), 0, 0]) {
        rotate (a=90.0, v=[1, 0, 0]) {
            cylinder (h=usbPortCenterCutLength, r=usb_c_z/2, center=true);
        }
    }
    
    translate ([usbPortCenter, 0, 0]) {
        cube ([usbPortCenterCut, usbPortCenterCutLength, usb_c_z], center=true);
    }
    
    translate ([(usbPortCenter + usbPortSideOffset), 0, 0]) {
        rotate (a=90.0, v=[1, 0, 0]) {
            cylinder (h=usbPortCenterCutLength, r=usb_c_z/2, center=true);
        }
    }
}

module usbRecessCutout() {
    usb_c_cover_plate = usb_holder_border;
    recess_y = (usb_holder_y - usb_elite_c_y - usb_holder_border - usb_c_cover_plate+3.5);
    recess_z = 8;
    translate ([0, (usb_holder_center_y - (recess_y / 2) +0.01), 0]) {
        
        translate ([0, 0, 0]) {
            rotate (a=90.0, v=[1, 0, 0]) {
                cylinder (h=recess_y, r=3.25, center=true);
            }
        }
        translate ([(+(usb_holder_center_x - (usb_elite_c_x/2)) - usb_holder_border), 0, 0]) {
            cube ([12.5, recess_y, recess_z], center=true);
        }
        translate ([(usb_c_x), 0, 0]) {
            rotate (a=90.0, v=[1, 0, 0]) {
                cylinder (h=recess_y, r=3.25, center=true);
            }
        }
    }
}

// main method
module usb_holder() {
    //adjust origin to front fact, bottom, mostly to match existing STLs
    translate([0, -(usb_holder_y/2), (usb_holder_z/2)]) {
        
        difference () {
            basicShape();
            trrsCutouts();
            eliteC();
            if (reset_holder) {
                resetCutout();
            }
            // translate([0.9, 0, 2.5])
            //     cube([1, 20, 5]);
            // translate([7, 0, 2.5])
            //     cube([1, 20, 5]);
            translate([-25, 0, 7])
                cube([100, 50, 50]);
        }
    }
}

usb_holder();

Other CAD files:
assets/mcu_holders/bastardkb/right/printable_shield.stl
assets/sockets/mx_hotswap.stl
assets/switches/kailh_choc.stl
things/boards/choc_skeletyl/choc_skeletyl_right.stl
assets/caps/KeyV2_DSS/DSS-R1.stl
assets/caps/KeyV2_DSS/DSS-R3.stl
assets/caps/KeyV2_DSS/DSS-R4.stl
assets/caps/KeyV2_DSS/DSS-R5.stl
assets/caps/KeyV2_OEM/OEM-R1.stl
assets/caps/KeyV2_OEM/OEM-R2.stl
assets/caps/KeyV2_OEM/OEM-R3.stl
assets/caps/KeyV2_OEM/OEM-R5.stl
assets/caps/KeyV2_SA/SA-R0.stl
assets/caps/KeyV2_SA/SA-R2.stl
assets/caps/KeyV2_SA/SA-R4.stl
assets/caps/KeyV2_cherry/cherry-R0.stl
assets/caps/KeyV2_cherry/cherry-R2.stl
assets/caps/KeyV2_cherry/cherry-R3.stl
assets/caps/KeyV2_matty3/matty3-deep-R0.stl
assets/caps/KeyV2_matty3/matty3-deep-R1.stl
assets/caps/KeyV2_matty3/matty3-deep-R2.stl
assets/caps/KeyV2_matty3/matty3-deep-R4.stl
assets/caps/KeyV2_matty3/matty3-deep-R5.stl
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

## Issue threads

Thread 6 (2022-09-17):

Closing walls between thumb cluster and main body

kagoromo, 2022-09-17:
Hi,

Firstly, thank you for making this generator available. I think you have managed to incorporate many great features that make building a Dactyl-like keyboard a lot easier. (For me those would be the compatibility with BastardKB's shield PCB and simple tent/eyelets generations).

I'm currently using a handwired Skeletyl with the original design from BastardKB. It works perfectly, but I have come to realize that I wanted a "closed" version to hide the wiring mess inside. Starting with the dometyl's version of the Skeletyl as well as the Closed Splaytyl, I managed to reach halfway there: The columns are now connected and fully closed, eyelets are in correct spots, so the only thing left to do is connecting the thumb cluster with the main body.

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

However, that last task turned out to be more difficult than I anticipated. My unfamiliarity with ocaml is the main roadblock to understand the Documentation fully, and I didn't really get anywhere just trying different Generator.Connect options, so I figured that I should look for help instead.

Here is my very crude first stab at a Closed Skeletyl. Please advise me on how to achieve my goal (if it's even possible at the moment). Thank you very much!

https://github.com/kagoromo/dometyl-keyboard/blob/3358873e1051f339ca1889142dceba54c9ed996e/dometyl/lib/boards/skeletyl_but_closed.ml

geoffder, 2022-09-19:
I'm afraid that proper full closure isn't something that it supports (somewhat of a non-goal for me, since the thumb is freed up to be more customizable without the extra stuff that might break). *However*, there is a bit more that you can do.

The [`~east_link`](https://github.com/kagoromo/dometyl-keyboard/blob/3358873e1051f339ca1889142dceba54c9ed996e/dometyl/lib/boards/skeletyl_but_closed.ml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) (and ~west_link) parameters let you control the connectors that run between the "first" thumb wall in the west and from the "last" back to the body in the west. The angles of the walls in the west make them a good candidate for a [`Connect.full_join`](https://github.com/geoffder/dometyl-keyboard/blob/9b33fecce617f6b6c7c55e9dfaa89c3a1183b5a3/dometyl/lib/generator/connect.mli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). a `full_join` might not work so nicely for the `~east_link`, but increasing the height of the connector there might give you more of the closed effect that you desire.

kagoromo, 2022-09-19:
@geoffder Thank you for your answer. It seems like the result I wanted is not achievable with the options available. Still, thank you for your work!

geoffder, 2022-09-19:
Ok, I'll go ahead and close this issue then.

Closed 2022-09-19.

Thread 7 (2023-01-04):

Splaytyl 1u pcb's compatibility

toniz4, 2023-01-04:
Hello!

I'm thinking about making a splaytyl keyboard with some slight changes, and I wish to use the 1u pcps that you showed in the Dartyl Choc Edition.

The 1u pcbs will be compatible with the splaytyl?

Thanks for developing this awesome project!

geoffder, 2023-01-04:
Yes you *should* be able to fit them in fine. Some areas may be a bit tight (I haven't done it myself), since the columns are jammed pretty close in to eachother, especially to accomodate the splayed columns. I don't think that it would be something that some post print processing can't get around though.

By the way, I've finally just merged in the upgrades to the generator I had on the backburner for a while, so I hope you can pull the changes and give it a try.

toniz4, 2023-01-04:
So I'm gonna try printing them. Either way I could resort to direct wire some keys too.

And something unrelated, I plan to use a xiao ble in my project, with a custom bastardkb adapter. So I will not be needing the trrs hole. I made some changes to the module that deals with that, making the trrs hole optional. Is that something you are interested in adding?

geoffder, 2023-01-05:
Yea making the trrs hole optional would be fine with me.

geoffder, 2023-01-11:
I've added a `?trrs` parameter to `BastardShield.make` to make the port hole optional: https://github.com/geoffder/dometyl-keyboard/commit/3cb13b18eb5e1284b75c40166a8301b5f6a8960c

Closed 2023-02-18.

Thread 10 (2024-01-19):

scad extension not added to generated files

krankydonkey, 2024-01-19:
All the base models and incl_ models are being generated, but only as plain files with no extension. This causes dune build @export_models to not work as well (I'm assuming) as it can't detect any .scad files

geoffder, 2024-01-19:
Thanks for the report. It's been a long time so I can't remember, but I think my helper `to_file` or equivalent used to add the `.scad` on the end to save the repetition. Guess I droppep it along the way cleaning things up. I'll try to push a fix soon, but in the meantime you can just add the extension to the names in `main.ml`.

krankydonkey, 2024-01-19:
It has been a while hey. I looked at this project a couple of years ago and
really liked it, but couldn't quite get the walls to generate properly.
Getting tired of having all the parts lying around and want to actually
finish it now though 😄

On Fri, 19 Jan 2024, 12:20 pm Geoff deRosenroll, ***@***.***>
wrote:

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

geoffder, 2024-01-19:
Nice, hope it works out for you this time! I'd like to revisit this and maybe make some improvements while making a new board, but it'll have to wait a bit longer.

krankydonkey, 2024-01-21:
Hey while I have you here, is there a way to set the wall generator back to
the old straight segments? I think I prefer that aesthetic to the new
rounded one.

On Fri, 19 Jan 2024 at 15:39, Geoff deRosenroll ***@***.***>
wrote:

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

geoffder, 2024-01-21:
Yeap, roundovers on the keyholes (which get swept into walls) are optional.

https://github.com/geoffder/dometyl-keyboard/blob/74671ba6ce1c03f679e8351e3c33ef6008171c63/models/examples/splaytyl.ml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

The `~corner` optional argument is a roundover function. If you remove it, the walls will have sharp corners like they used to. You can also do chamfering, I'd you'd prefer that (see skeletyl example).
https://github.com/geoffder/dometyl-keyboard/blob/74671ba6ce1c03f679e8351e3c33ef6008171c63/models/examples/skeletyl.ml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

krankydonkey, 2024-01-22:
I've deleted the ~corner options, and it solves a small section of the
sweep, but I was more talking about the main wall section, which are still
very rounded. I'm trying to get it to look like the ones in the first
picture of the github.

On Mon, 22 Jan 2024 at 08:56, Geoff deRosenroll ***@***.***>
wrote:

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

geoffder, 2024-01-22:
Do you mean the connectors that run along the ground, connecting the walls? There is another `~corner` for those here:
https://github.com/geoffder/dometyl-keyboard/blob/74671ba6ce1c03f679e8351e3c33ef6008171c63/models/examples/splaytyl.ml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

Also, you might be wanting to get rid of the fillets, which should be able to be done (sorry don't have time to test) by giving ```~fillet_h:(`Abs 0.)``` in the application of `Connect.skeleton`.

krankydonkey, 2024-01-22:
Sorry, I should have included an image. I mean these curves. You can see
deleting the ~corner options has changed the little segment on the top
right, but the rest of the connector/wall is still swept.

[image: curve.png]

On Mon, 22 Jan 2024 at 11:40, Geoff deRosenroll ***@***.***>
wrote:

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

geoffder, 2024-01-22:
It seems that the image did not make the trip via email.

krankydonkey, 2024-01-22:
dang. How about as an attachment

On Mon, 22 Jan 2024 at 12:13, Geoff deRosenroll ***@***.***>
wrote:

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

geoffder, 2024-01-22:
Afraid not. Taking a guess at what it's about though in the mean time:

For the connectors along the ground, splines are the only option now besides joining the whole height of the wall. Playing with the parameters might get some of the angular look you want back though, like turning `~fn` way down (number of points in the spline path). When I was updating I was having trouble coming to a solution for straight connections that I was happy with so I just went with splines (for then, which has lasted until now) since they were less likely to break.

Closed 2024-01-19.

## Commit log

2021-04-17 Dune skeleton and scad output
    [case.scad]
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2021-05-02 WIP Niz platform and hole adjustments
    [case.scad]
2021-05-07 Add clearance for snap slot (to be tuned).
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2021-05-09 Sensor printing fixes. - notch from pillars
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2021-06-04 + outer wall coverage of the snap slot (stronger)
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2021-07-12 Fix wall overlap case + fill wedges in join_walls
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2021-08-04 Add ability to preview with keycaps
    [SA_R3.stl]
2021-08-05 Thumb related tweaking
    [SA-R3.stl]
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2021-08-07 Increased default clearance. Add screw conf option
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2021-08-14 Tighthen up M4 heat insert radius
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2021-08-22 BK skeletyl stl for comparison
    [bk_skeletyl_v3_v5.stl]
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2021-08-24 Choc support additions
    [MBK_darryldh_1u.stl]
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2021-08-29 Reorg into sublibraries + things folder reorg
    [MBK_darryldh_1u.stl, SA-R3.stl, bastardkb_skeletyl_v3_v5.stl]
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2021-08-31 Carbonfet holder stls
    [elite-c_holder.stl, pro_micro_holder.stl, shim.stl]
2021-09-01 Tighten up column spacing
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2021-09-01 Reorg holders, + dereknheiley reversible holder
    [elite-c_holder.stl, elite-c_holder_w_reset.stl, pro_micro_holder.stl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]
2021-09-01 WIP bastardkb sheild pcb support
    [elite-c_shield.dxf]
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2021-09-03 Add note about main.ml.example
    [elite-c_shield.dxf]
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2021-09-04 Corrected sockets
2021-09-06 Hotswap socket implentation
    [choc_hotswap_socket.stl, kailh_choc.stl]
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2021-09-07 Fix socket hole cutout
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2021-09-07 svg for holes + printable shield for mounting
    [printable_shield.stl]
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2021-09-07 Fix hole
    [printable_shield.stl]
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2021-09-09 Reorganize. Add (inaccurate?) mx socket model
    [choc_hotswap_socket.stl, kailh_choc.stl, mx_hotswap_socket.stl]
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2021-09-16 Rest of SA rows, and MT3 clone
    [SA-R0.stl, SA-R2.stl, SA-R3.stl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]
2021-09-16 Add cap profiles and org consistency
    [DSA-R3.stl, MBK_1u.stl, OEM-R1.stl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]
2021-09-17 Add DSS. MBK consistency
    [DSS-R1.stl, DSS-R2.stl, DSS-R3.stl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]
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2021-09-18 Example stls of latest splaytyl prototype
    [splaytyl_hotswap_left.stl, splaytyl_hotswap_right.stl, splaytyl_right.stl]
2021-09-18 Base plate and tent for proto splaytyl
    [splaytyl_base_right.stl, splaytyl_tent_30deg_right.stl]
2021-09-19 Splaytyl adjustments
    [splaytyl_base_right.stl, splaytyl_hotswap_left.stl, splaytyl_hotswap_right.stl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]
2021-09-19 Choc spin on skeletyl
    [choc_skeletyl_hotswap_left.stl, choc_skeletyl_hotswap_right.stl, choc_skeletyl_right.stl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]
2021-09-20 Example board stls and images
    [splaytyl_right.stl]
2021-09-20 Fix stl link
2021-09-20 Increased cap height, adjusted to compensate
    [choc_skeletyl_hotswap_left.stl, choc_skeletyl_hotswap_right.stl, choc_skeletyl_right.stl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]
2021-09-21 Enable bumpon insets starting in wall.
    [choc_skeletyl_hotswap_left.stl, choc_skeletyl_hotswap_right.stl, choc_skeletyl_right.stl]
2021-09-21 Move shield 0.5 in to the case
    [choc_skeletyl_hotswap_left.stl, choc_skeletyl_hotswap_right.stl, choc_skeletyl_right.stl]
2021-09-23 Adjust to cap height fixes
    [choc_skeletyl_hotswap_left.stl, choc_skeletyl_hotswap_right.stl, choc_skeletyl_right.stl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]
2021-09-24 Update stls with wall join improvements
    [choc_skeletyl_hotswap_left.stl, choc_skeletyl_hotswap_right.stl, choc_skeletyl_right.stl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]
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2021-09-24 Updated with shifted in thumb
    [choctyl_30deg_tent_right.stl, choctyl_hotswap_left.stl, choctyl_hotswap_right.stl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]
2021-09-24 Fix port corner cut hole
    [choctyl_hotswap_left.stl, choctyl_hotswap_right.stl, choctyl_right.stl]
2021-09-25 Add (mostly) closed case STLs of the splaytyl
    [closed_splaytyl_30deg_tent_right.stl, closed_splaytyl_base_right.stl, closed_splaytyl_hotswap_left.stl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]
2021-09-27 Add pseudoku DES caps
    [DES-R1.stl, DES-R2.stl, DES-R3-deep.stl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]
2021-09-27 Add chicago steno caps
    [Chicago-R2-R4.stl, Chicago-R3-chord.stl, Chicago-R3-flat.stl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]
2021-09-28 Rotate thumb clips, north sockets. + minor changes
    [choctyl_30deg_tent_right.stl, choctyl_hotswap_left.stl, choctyl_hotswap_right.stl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]
2021-09-28 North facing sockets and rotated thumb clips
    [choc_skeletyl_hotswap_left.stl, choc_skeletyl_hotswap_right.stl, choc_skeletyl_right.stl]
2021-09-29 Move up default shield offset
    [splaytyl_hotswap_left.stl, splaytyl_hotswap_right.stl, splaytyl_right.stl]
2021-09-29 Increase default screw head and bumpon inset radii
    [splaytyl_base_right.stl, splaytyl_tent_30deg_right.stl]
2021-09-29 Updated shield position. Incr sink + bumpon radii
    [choctyl_30deg_tent_right.stl, choctyl_hotswap_left.stl, choctyl_hotswap_right.stl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]
2021-09-29 Raise shield position slightly
    [choc_skeletyl_hotswap_left.stl, choc_skeletyl_hotswap_right.stl, choc_skeletyl_right.stl]
2021-09-30 Configurable screw clearance cuts
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2021-10-01 Screw clearance example
    [choctyl_30deg_tent_right_w_clearance.stl]
2021-10-01 Longer clearance cuts
    [choctyl_30deg_tent_right_w_clearance.stl]
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2021-10-01 Choctyl example reconfigured to use 6x2 magnets
    [choctyl_30deg_tent_right.stl, choctyl_30deg_tent_right_w_clearance.stl, choctyl_hotswap_left.stl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]
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2021-10-24 Fix reversible_holder rail positioning
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2021-10-25 Adjust through hole package size / tolerance
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2021-11-04 More bumpons for greater stability
    [choc_skeletyl_hotswap_left.stl, choc_skeletyl_hotswap_right.stl, choc_skeletyl_right.stl]
2021-11-05 Re-increase sensor depth (glue and print tolerances)
2021-11-08 Add missing left side (not-mirrorable).
    [printable_shield.stl, printable_shield_left.stl, printable_shield_right.stl]
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2021-11-09 Clear out unused images
    [choc_assembly.scad]
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2021-11-09 Minor screw clearance in tent
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2021-11-10 The dartyl choc edition
    [dartyl_choc.stl, usb_holder.scad, usb_holder_promicro_usbc.stl]
2021-11-10 Update choctyl config and refresh stls/readme
    [choctyl_20deg_tent_right.stl, choctyl_30deg_tent_right.stl, choctyl_hotswap_left.stl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]
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2023-01-04 Merge in #revamp (squashed)
    commit 4fdf30a1e4fef278255b50cd54af7640f132818f
    Author: Geoff deRosenroll <geoffderosenroll@gmail.com>
    Date: Wed Jan 4 15:27:35 2023 -0800
    + doc comments and guide extension
    commit 6968e8be4f02a689a27f06324f784e842e0e2796
    Author: Geoff deRosenroll <geoffderosenroll@gmail.com>
    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
    [Chicago-R2-R4.stl, Chicago-R3-chord.stl, Chicago-R3-flat.stl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]
2023-01-06 Bandaid fix for faulty hulling (needs fix in OCADml)
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2023-01-06 Add new splaytyl example stls
    [splaytyl_base_right.stl]
2023-01-07 Various fixes + example stl uploads
    [choc_skeletyl_right.stl, niztyl_base_right.stl]
2023-01-07 Use custom splaytyl plate (better bumpons)
    [splaytyl_base_right.stl]
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
